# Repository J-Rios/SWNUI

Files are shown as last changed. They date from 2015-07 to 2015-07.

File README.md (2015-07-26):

# SWNUI
Simple Wireless Natural User Interface (Final Degree Project)

Inside the world of electronics there is a large diversity of fields, from among all, in this Final Degree Project, we will focus in the ambit of the human-machine interaction.

We will proceed then, to perform the prototype of a simple natural user interface that is able to make a wireless communication with an extern system, in our case a PC. To do that, we will use a microcontroller based system that will process the acquired reads from an accelerometer and determines the gesture accomplished to transmit it later through a Bluetooth link to the reception system.

In that way, we will start by implementing the hardware design of the system, designing the electrical schematic and the CAD design of the printed circuit board (by using the Eagle software), manufacturing the board and doing the components solder process. Once completed the hardware of the system we will continue with the software design, at both side of the system: the prototype manufactured and the extern system (PC), that allows verify the correct functionality of the system.

Complementary to the hardware and software development, we will work out the 3D model of the prototype enclosure (by using the Freecad software).

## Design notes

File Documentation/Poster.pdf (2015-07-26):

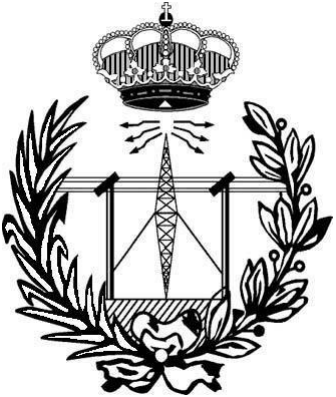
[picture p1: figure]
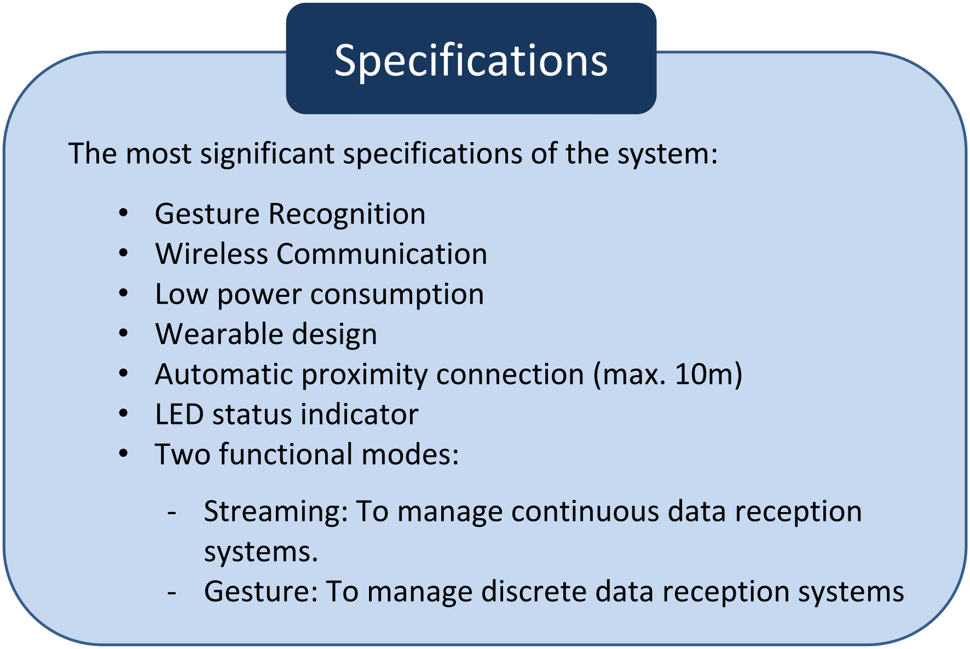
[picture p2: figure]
Specifications; • Gesture Recognition • Wireless Communication • Low power consumption • Wearable design; • LED status indicator • Two functional modes:; systems.

Inside the world of electronics there is a large diversity of fields, in this Final Degree Project, we will focus in the ambit of the human-machine interaction.
We will perform the prototype of a simple natural user interface that is able to recognizes hand gestures and control an extern system by wireless communication. To do that, we will use a microcontroller based system that will process the acquired reads from an accelerometer and determines the gesture accomplished to transmit it later through Bluetooth Low Energy link to the reception system.
We will start by implementing the hardware design of the system, designing the electrical schematic and the CAD design of the printed circuit board, manufacturing the board and doing the components solder process. Once completed the hardware of the system we will continue with the software design, at both side of the system: the prototype manufactured and the extern system (We will control the mouse and keyboard of a PC), that allows verify the correct functionality of the system.
Complementary to the hardware and software development, we will work out the 3D model of the prototype enclosure.

# Gesture Recognition System (Simple Wireless Natural User Interface)

## -José Miguel Ríos Rubio-

## Abstract

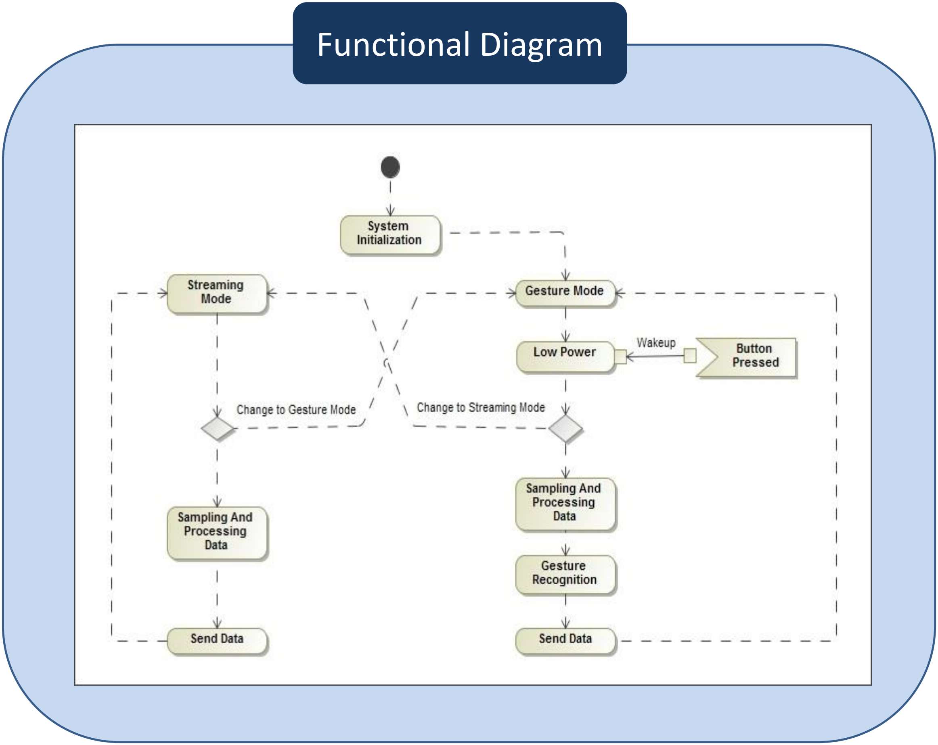
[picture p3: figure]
Functional Diagram
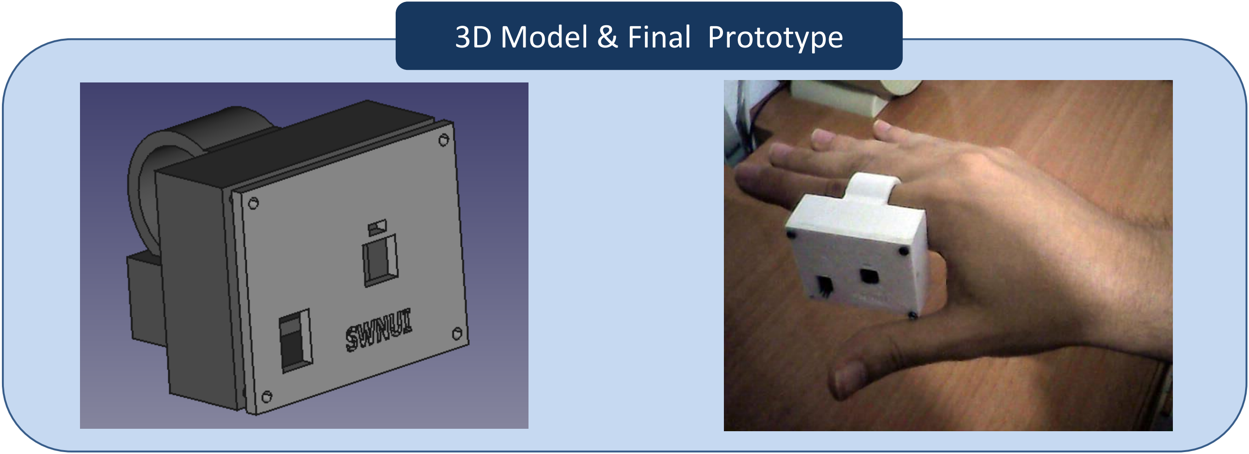
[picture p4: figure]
3D Model & Final Prototype
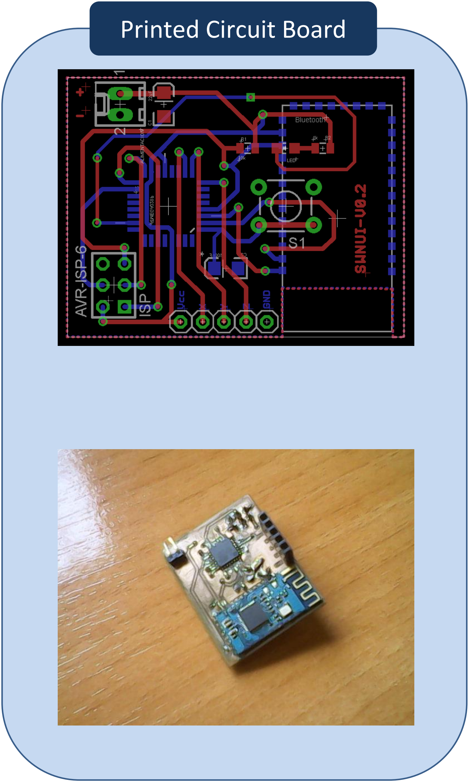
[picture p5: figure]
Printed Circuit Board

## Conclusions, Future Work and Repository

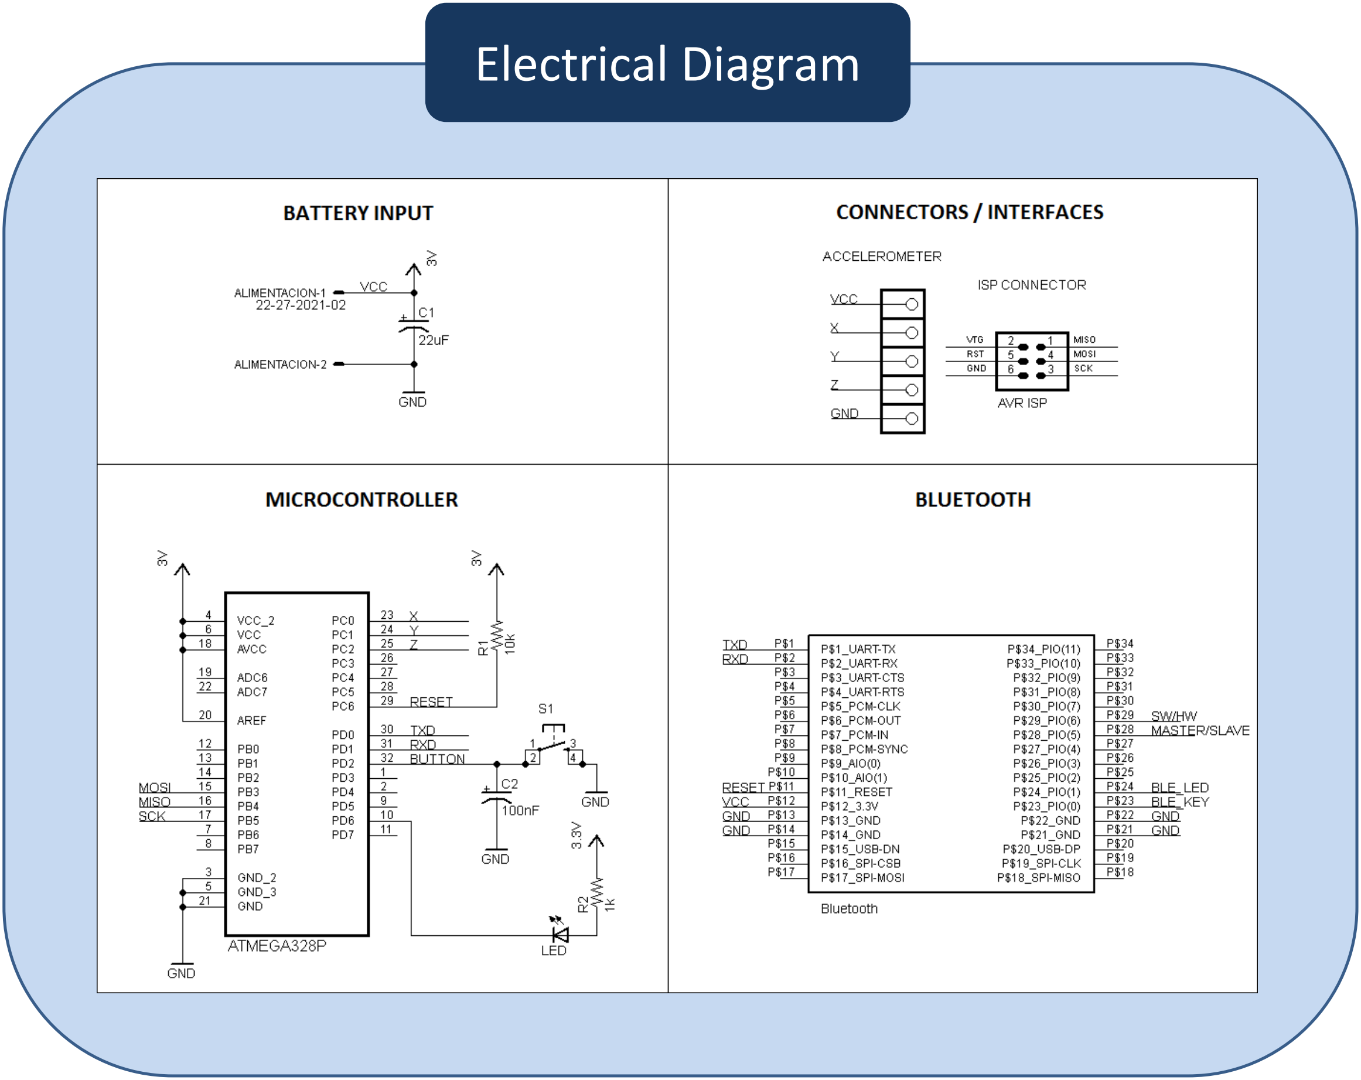
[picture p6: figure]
Electrical Diagram

## Future work

- Improve the low power of the system.
- Improve the mechanical part of the system (size and appearance).
- Design a SOC solution for all the system (Combine accelerometer, BLE and custom functionality).
- Transform the prototype into a final product.

## Departamento Tecnología Electrónica E.T.S.I Telecomunicación, Universidad de Málaga Trabajo Fin de Grado del Grado en Ingeniería de Sistemas Electrónicos. Julio 2015

The most significant specifications of the system:

- Automatic proximity connection (max. 10m)
- Streaming: To manage continuous data reception
- Gesture: To manage discrete data reception systems

## Conclusions

- IMU based solutions beats optical systems for gesture recognition (no need direct vision).
- Gesture recognition will become an important part of the wearables devices.
- NUIs will increase their importance in society (due rise of the wearable and low size MEMs technologies).

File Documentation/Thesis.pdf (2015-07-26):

## UNIVERSIDAD DE MÁLAGA

## ESCUELA TÉCNICA SUPERIOR DE INGENIERÍA DE TELECOMUNICACIÓN

## TRABAJO FIN DE GRADO

## SISTEMA DE RECONOCIMIENTO GESTUAL

GRADO EN INGENIERÍA DE
SISTEMAS ELECTRÓNICOS

JOSÉ MIGUEL RÍOS RUBIO
MÁLAGA, 2015

E.T.S. DE INGENIERÍA DE TELECOMUNICACIÓN, UNIVERSIDAD DE MÁLAGA

Título del Trabajo Fin de Grado

Autor: José Miguel Ríos Rubio

Tutor: Francisco Javier Vizcaíno Martín

Departamento: Departamento de Tecnología Electrónica

Titulación: Grado en Ingeniería de Sistemas Electrónicos

Palabras clave: Diseño hardware, Desarrollo software, Diseño CAD 3D, Sistema basado en microcontrolador, Sistema de interacción natural, Bluetooth Low Energy, Unidad de medida inercial (IMU)

Resumen

Dentro del mundo de la electrónica existe una gran diversidad de campos, de

entre todos ellos, en este trabajo fin de grado, nos centraremos en el ámbito de

la interacción humano-máquina.

Se procederá pues, a realizar el prototipo de un dispositivo de interacción

natural simple capaz de comunicarse de forma inalámbrica con un sistema

externo, en este caso un PC. Para ello, se recurrirá al uso de un sistema

basado en microcontrolador que procesará la lectura obtenida de un

acelerómetro y determinará el gesto realizado para, posteriormente, transmitirlo

a través de un enlace bluetooth al sistema receptor.

De este modo, comenzaremos por realizar el diseño hardware del sistema,

diseñando el esquema eléctrico y el diseño CAD de la placa de circuito impreso

(mediante el uso de la herramienta Eagle), para finalizar con el desarrollo de la

placa y el proceso de soldadura de componentes. Una vez finalizado el

hardware del sistema nos ocuparemos del diseño software, tanto de la parte

correspondiente al prototipo desarrollado como de la parte localizada en el PC,

la cual nos permitirá verificar el correcto funcionamiento del sistema.

Complementariamente al desarrollo hardware y software, crearemos el modelo

3D (gracias al software Freecad) de la carcasa que albergará al prototipo.

E.T.S. DE INGENIERÍA DE TELECOMUNICACIÓN, UNIVERSIDAD DE MÁLAGA

English version of the title

Author: José Miguel Ríos Rubio

Supervisor: Francisco Javier Vizcaíno Martín

Department: Departamento de Tecnología Electrónica

Degree: Grado en Ingeniería de Sistemas Electrónicos

Keywords: Hardware design, Software development, 3D CAD design, Microcontroller based system, Natural user interface system, Bluetooth Low Energy, Inertial measurement unit (IMU)

Abstract

Inside the world of electronics there is a large diversity of fields, from among all,

in this Final Degree Project, we will focus in the ambit of the human-machine

interaction.

We will proceed then, to perform the prototype of a simple natural user interface

that is able to make a wireless communication with an extern system, in our

case a PC. To do that, we will use a microcontroller based system that will

process the acquired reads from an accelerometer and determines the gesture

accomplished to transmit it later through a Bluetooth link to the reception

system.

In that way, we will start by implementing the hardware design of the system,

designing the electrical schematic and the CAD design of the printed circuit

board (by using the Eagle software), manufacturing the board and doing the

components solder process. Once completed the hardware of the system we

will continue with the software design, at both side of the system: the prototype

manufactured and the extern system (PC), that allows verify the correct

functionality of the system.

Complementary to the hardware and software development, we will work out

the 3D model of the prototype enclosure (by using the Freecad software).

# Agradecimientos

Haber llegado al punto de mi vida en cual me encuentro no ha sido un camino

fácil, no obstante, gracias a todas aquellas personas que han estado presente

a lo largo de mis estudios, ese camino se vio suavizado y se hizo más ameno.

Familia, amigos, compañeros, profesores… por vuestro tiempo, ayuda,

consejos y apoyo, gracias.

i

## Contenido

ii

iii

# Lista de Acrónimos

ADC | Analog-Digital Converter
BLE | Bluetooth Low Energy
CAD | Computer Aided Design
CNC | Control Numérico Computarizado
DOF | Degrees Of Freedom
DSP | Digital Signal Processing
FPGA | Field Programmable Gate Array
GPIO | General Purpose Input/Output
GPS | Global Positioning System
I2C | Inter-Integrated Circuit
ICSP | In Circuit Serial Programming
IDE | Integrated development environment
IMS | Inertial Measurement System
IMU | Inertial Measurement Unit
LED | Light Emitting Diode
MEMs | Microelectromechanical systems
PC | Personal Computer
PCB | Printed Circuit Board

iv

PCI | Placa de Circuito Impreso
POO | Programación Orientada a Objetos
RF | Radio Frecuencia
RTI | Rutina de Tratamiento de Interrupción
SMD | Surface Mounted Device
SPI | Serial Peripheral Interface
SWNUI | Simple Wireless Natural User Interface
TFG | Trabajo Fin de Grado
TPV | Terminal Punto de Venta
UART | Universal Asynchronous Receiver-Transmitter
UMA | Universidad de Málaga
USB | Universal Serial Bus

# Capítulo 1. Introducción

Desde el surgimiento de la especie humana y, mucho antes de la evolución del

lenguaje, la comunicación no verbal nos ha acompañado hasta hoy día. No obstante, el

estudio de ésta no alcanza una importancia digna de mención hasta la década de 1950,

en la que en el año 1952, el antropólogo Ray Birwhistell escribió “Introduction to

kinesics” [1], el cual es considerado como uno de los iniciales estudios modernos sobre

comunicación | no | verbal. | Ray | Birwhistell | acuñó | el | término | “kinesics”

(“kinésica”/”cinésica” en castellano), proveniente del griego kinesis, que significa

movimiento, para referirse al estudio del movimiento humano. De este modo, la

kinésica, junto con la “proxémica” (estudio de la forma de uso del entorno por parte de

la persona a la hora de comunicarse) y la “paralingüística” (estudio de las cualidades no

verbales de la voz) componen la base principal del lenguaje no verbal. Con lo cual, los

gestos pueden clasificarse en resumidas cuentas dentro de la “kinésica” del lenguaje

no verbal.

Se entiende como reconocimiento gestual la adquisición e interpretación de

movimientos de carácter expresivo del cuerpo o de partes del mismo. De esta forma, se

debe diferenciar claramente entre un movimiento, que puede o no tener significado, y

un gesto, cuyo carácter significativo se encuentra intrínsecamente ligado a su acción.

Normalmente, los gestos presentan la funcionalidad de permitir la comunicación no

verbal entre dos seres que comparten la misma interpretación para el conjunto de

señales que conforman el lenguaje gestual, y decimos “normalmente” pues suele haber

casos en los que el gesto suele ir acompañado de algún sonido característico

("paralingüismo"). Una clara distinción entre comunicación verbal y no verbal radica en

el hecho de que el primero es utilizado para comunicar información mientras que el

Capítulo 1. Introducción

segundo es usado para comunicar estados de ánimo y/o actitudes respecto a un

acontecimiento.

## 1.1. Contexto tecnológico

Determinar la posición y el movimiento en el espacio de una entidad es de gran importancia para una gran variedad de aplicaciones. Si observamos hoy día el mercado actual nos encontramos en medio de una batalla comercial en la que se intenta hallar qué sistema de captura y reconocimiento de movimiento es el más eficientemente aceptado por la sociedad y, consecuentemente, el más exitoso.

Las empresas relacionadas con los videojuegos fueron las que, en primera instancia, se abrieron paso en este mundo en busca de la mejora en la experiencia de juego de los usuarios, intentando encontrar una interfaz con la que el jugador pudiera interaccionar de forma innovadora y más cercana a la realidad. Entre los dispositivos más reconocidos y que mayor impacto han tenido se encuentran, entre otros (figura 1), el Sensor Kinect [2] de Microsoft, lanzado el 4 de noviembre de 2010 [3], que entró en el “Guinness World Records” (Libro Guinness de los Records) por ser el periférico de juego vendido más rápidamente tras vender una media de 133.333 unidades por día en sus primeros 60 días [4]. Básicamente, este dispositivo es un periférico de control para la videoconsola Xbox 360, aunque posteriormente se adaptase para su uso en PC con sistemas operativos Windows 7 y Windows 8. El Sensor Kinect se encuentra en competencia directa con el Wii Remote [5] de Nintendo y el PlayStation Move [6] de PlayStation de los que hablamos a continuación.

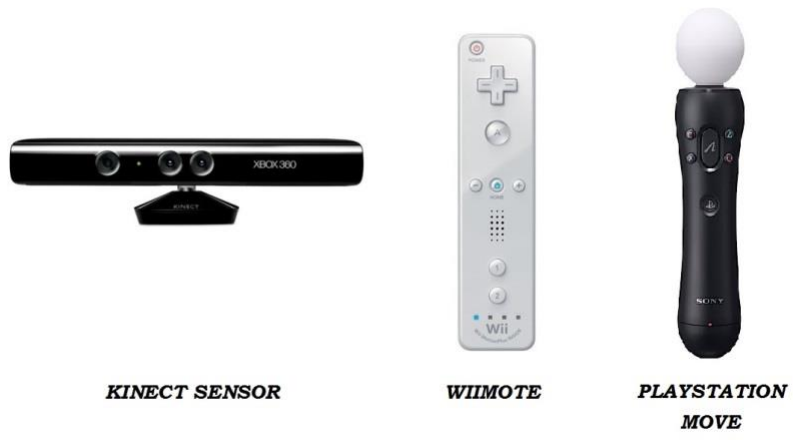
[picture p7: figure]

Figura 1. Dispositivos de reconocimiento gestual (Kinect, Wiimote y PlayStation Move).

El Wii Remote fue desarrollado como periférico de control de la videoconsola Nintendo Wii y, apareció en el mercado junto con esta, el 19 de noviembre de 2006 [7].

Introducción

Por otro lado, el PlayStation Move es un sistema conformado por un dispositivo de control, Motion Controller, y un dispositivo basado en una cámara, PlayStation Eye, que se encarga de obtener la posición del dispositivo de control. El sistema salió al mercado el 17 de septiembre de 2010 [6].

Sin embargo, no solo las empresas dedicadas al entretenimiento están interesadas en el uso de este tipo de sistemas de reconocimiento de movimiento. Determinar la posición y el movimiento en el espacio de una entidad es de gran importancia para una gran variedad de aplicaciones en distintos campos. Parte de la característica más destacable de los teléfonos inteligentes (Smartphones) de hoy en día consiste en la detección de la orientación, inclinación y aceleración que sufren, todo esto es gracias a la incorporación de dichos sistemas de reconocimiento en estos dispositivos. Así mismo, un gran número de aplicaciones robóticas se basan en el uso de estas tecnologías sensoriales para realizar el control del movimiento de las distintas partes del robot o mecanismo asociado. Esto se extiende desde el manejo de Drones (vehículos aéreos no tripulados controlados remotamente) en aplicaciones militares, control de un robot de alta precisión para realizar operaciones quirúrgicas (campo de medicina y salud) como el Sistema Quirúrgico Da Vinci [8], dispositivos de ayuda a la navegación de vehículos (sobre todo aéreos), etc.

En la actualidad, el reconocimiento gestual se encuentra extendido entre dos tipos de tecnologías de adquisición e interpretación de gestos: las basadas en “cámara”, las cuales pueden considerarse ópticas, que requieren de un procesamiento gráfico y, por consiguiente, de visión directa del gesto (como el Sensor Kinect y el PlayStation Move), y los basados en sistemas de “unidad de medida inercial” (IMU, de sus siglas en inglés “Inertial Measurement Unit”), no ópticas, como el Wii Remote.

Los sistemas “ópticos” de reconocimiento de movimiento pueden o no servirse de algún dispositivo auxiliar al que realizar el seguimiento y determinar el movimiento realizado (como en el caso del Motion Controller de PlayStation) o no (Kinect de Microsoft), dado que estos sistemas están ampliamente ligados más al algoritmo software de reconocimiento y procesado de imagen. Cuanto más complejo sea dicho procesado mayor potencia tendrá el sistema. De esta forma, el Sensor Kinect es un dispositivo cuyo procesado de reconocimiento es tan potente que permite reconocer no solo al usuario que está interactuando, sino obtener cada uno de los movimientos realizados por este. No obstante, y como es de esperarse debido a que el sistema requiere de visión directa, si el usuario oculta sus manos tras la espalda y realiza algún movimiento con ellas esto no será detectado por el sistema.

En contraposición, las unidades de medida inercial o IMUs son dispositivos electrónicos que albergan un conjunto de sensores que permiten identificar al dispositivo en el

Capítulo 1. Introducción

espacio mediante la adquisición de ciertos parámetros de aceleración, inclinación, orientación y posición. Para ello, estos sistemas pueden presentar diferentes tipos de sensores: acelerómetros, giroscopios, magnetómetros (basados en tecnologías de sistemas microelectromecánicos, MEMs), barómetros e incluso GPS (Sistema de posicionamiento global).

Los acelerómetros son sistemas capaces de medir la aceleración lineal, los giroscopios permiten determinar la velocidad angular, los magnetómetros permiten detectar campos magnéticos (como el de la Tierra), los barómetros indican la presión barométrica (en relación a la altitud) y el GPS determina la posición del sistema según las coordenadas terrestres de longitud, latitud y altitud, así como de proveer de parámetro temporal al sistema (tiempo).

Según la presencia de dichos sensores en la IMU y el número de ejes de medida de tales elementos, un sensor inercial puede ser clasificado, según los grados de libertad, por las siglas DOF (“Degrees of freedom”) del mismo. Así, si una IMU tiene 6 DOF, ésta suele estar compuesta por un acelerómetro y un giroscopio de 3 ejes cada uno (‘X’, ‘Y’ y ‘Z’). En caso de que la IMU sea de 9 DOF, el sistema contendrá a su vez un magnetómetro.

Figura 2. Ejemplo de IMU de 11 DOF (Con GPS y Barómetro incluidos).

Puede considerarse que cualquier extremidad del cuerpo humano tiene como máximo 6 grados de libertad de movimiento, que permiten determinar la posición y orientación de esa parte en el espacio.

Todo avión que sobrevuela en la actualidad nuestros cielos presenta un sistema de medición inercial (IMS), el cual cuenta con una unidad de medida inercial (IMU) para

Introducción

corregir la inclinación (de forma automática) y, por tanto detectar cualquier malfuncionamiento, como avisar al piloto de cualquier peligro existente.

Conociendo estos dos tipos de tecnologías de reconocimiento de movimiento, podemos volver a analizar los productos de entretenimiento antes expuestos (Kinect, Wii Remote y PlayStation Move) para determinar cuál tecnología es aplicada a cada uno de ellos. De esta forma, el Sensor Kinect está basado exclusivamente, como ya hemos dicho, en el reconocimiento óptico, el Wii Remote por el contrario, es un sistema puramente basado en IMU, mientras que el PlayStation Move representa la fuerza de la unión de ambas tecnologías en el mismos sistema (sistema híbrido) ya que su Motion Controller presenta una IMU que determina aspectos de movilidad semejantes a los del Wii Remote mientras que, el PlayStation Eye, añade un reconocimiento visual de nuestros movimientos.

## 1.2. Objetivos del Trabajo Fin de Grado

Visto todo lo anterior, el objetivo principal de este trabajo fin de grado consiste en

realizar un sistema de interacción natural de usuario (NUI, del inglés Natural User

Interface) simple y de bajo coste. Para ello se procederá al desarrollo del prototipo de

un elemento capaz de registrar e interpretar un conjunto de simples gestos

(movimientos e inclinaciones), realizados por la mano del usuario, con el fin de

controlar de forma inalámbrica diversos sistemas externos sin que exista una visión

directa entre la mano y el sistema.

## 1.3. Estructura de la Memoria

El documento presente se encuentra dividido en varios capítulos que muestran el conjunto de contenidos desarrollados para realizar la implementación del sistema. A continuación, se procede a describir el contenido de cada uno de esos capítulos, de esta forma:

- En el primer capítulo (“Introducción”), el presente, se ha hablado del ámbito de este Trabajo Fin de Grado (TFG). Se ha intentado dar una pincelada muy general del TFG, comenzando por el desarrollo de una breve introducción relativa a la temática del proyecto, el contexto tecnológico actual de diversas tecnologías y productos relacionados con el sistema a desarrollar y acabando con los objetivos principales de dicho sistema y la estructura del documento.

Capítulo 1. Introducción

- El capítulo segundo (“Especificaciones del sistema”), concierne a las especificaciones del sistema donde, analizando el objetivo que debe cumplir el mismo, se fijan las características que presentará el sistema y se establecen los requisitos que se pretenden cumplir.
- En el tercer capítulo (“Desarrollo del sistema”), se determina los componentes a utilizar para el diseño del sistema y se muestra todo el proceso de diseño y desarrollo y fabricación del prototipo del sistema realizado, pasando por el hardware, el software y el diseño CAD de la carcasa.
- En el capítulo cuarto (“Verificación y pruebas”) se define el conjunto de pruebas a realizar sobre el sistema desarrollado, el proceso de realización de tales pruebas y el resultado de las mismas, verificándose así la correcta funcionabilidad del sistema y el cumplimiento de los objetivos y especificaciones del proyecto.
- El quinto capítulo (“Manual de instalación y uso”), alberga el contenido relacionado con la instalación, puesta en marcha y utilización del sistema mediante la redacción de ciertos manuales de usuario.
- El capítulo sexto (“Conclusiones y trabajo futuro”) expone el conjunto de experiencias adquiridas en la realización del proyecto, así como un análisis de prestaciones del sistema, indicando las posibles mejoras que se podrían incorporar al prototipo realizado.

# Capítulo 2. Especificaciones del sistema

Dado que nuestro sistema es un dispositivo de interacción natural (NUI) que

nos va a permitir determinar gestos simples y comunicarlos de forma

inalámbrica, se le dará al sistema el nombre SWNUI (Simple Wireless Natural

User Interface) de aquí en adelante.

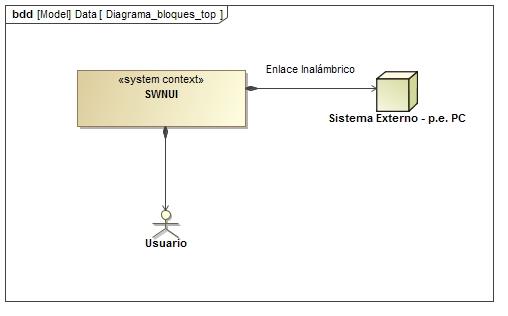
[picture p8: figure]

Figura 3. Contexto del sistema.

Según el objetivo de nuestro proyecto, el sistema permitirá el reconocimiento

de los gestos realizados con la mano sin la necesidad de que exista visión

directa entre el elemento de control y el sistema a controlar. Además, el

sistema deberá ser capaz de comunicarse de forma inalámbrica con ese

Capítulo 2. Especificaciones del sistema

elemento externo (figura 3). Lo que nos lleva a acotar ciertas características

que poseerá nuestro sistema:

- Podemos determinar que, dado que no se precisa visión directa, el tipo

de tecnología a utilizar será el basado en IMUs (tecnología “no óptica”).

- Ya que los gestos a registrar se realizan con la mano, sabemos que el

IMU se debe situar en algún punto de la misma.

- La comunicación deberá ser inalámbrica y de un rango de alcance

medio/alto. Entre ellos podría usarse RF, bluetooth, Zigbee, wifi, etc.

Por otro lado, el sistema buscará la armonía entre bajo consumo y tamaño

reducido para satisfacer la tendencia actual hacia la creación de dispositivos

wearables (“vestibles”):

- Esto implica que el sistema deberá encontrarse en un estado de bajo

consumo el máximo tiempo posible y se activará para realizar el proceso

de registro, procesado y envío del gesto realizado.

- La activación del sistema, por tanto, no dependerá del movimiento

realizado sino que se llevará a cabo a partir de un pulsador.

- Dado que el sistema será de pequeño tamaño y wearable, el pulsador

de activación se debe localizar en una posición confortable para la

pulsación por el usuario (que se evite el tener que recurrir a la otra mano

para su uso), determinamos que la posición óptima del sistema se

encontrará en el dedo índice de la mano, con pulsación mediante el

dedo pulgar (figura 4).

- El bajo consumo junto al bajo coste limitaría el tipo de tecnología de

comunicación inalámbrica a utilizar: RF, BLE…

Figura 4. Pulsador en posición confortable.

Capítulo 2. Especificaciones del sistema

Analizando el objetivo del sistema en sí, podemos apreciar que, registrar los

datos de movimientos e inclinaciones realizados continuamente es un paso

previo a la obtención del gesto realizado, por lo que si el sistema que queremos

controlar es un sistema dinámico (requiere un flujo continuo de datos para su

control, por ejemplo controlar el movimiento de un robot o un dron, o manejar el

cursor de un ordenador) incluir un modo de funcionamiento continuo,

conmutable con el modo de envío de gestos, no es mala idea:

- Por tanto, se implementarán dos modos de funcionamiento del sistema,

el modo de envío continuo de datos y el modo de envío de gestos.

- El modo de funcionamiento debe ser señalizado para el usuario, por

ejemplo mediante un LED.

- Dado que el sistema incluye un pulsador para salir del bajo de consumo,

con el fin de no incrementar el coste, éste también se utilizará para

realizar el cambio entre modos.

Analizando más detenidamente la tecnología necesaria tanto para el IMU,

como para el enlace inalámbrico, conseguimos determinar que:

- Como los gestos a registrar son sencillos (inclinación y movimiento), el

IMU se reduce a un simple acelerómetro de tres ejes.

- Ya que el sistema debe de ser de bajo consumo y la velocidad de

transmisión de datos no necesita ser muy alta, la comunicación

inalámbrica se puede satisfacer mediante Bluetooth Low Energy (BLE).

Los movimientos voluntarios de una mano suelen ser inferiores a los 7 Hz [9],

por lo que la frecuencia de muestreo deberá ser superior a los 14 Hz (para

cumplir con el teorema de Nyquist). De este modo, la frecuencia no será una

limitación a la hora de seleccionar el elemento de procesamiento de nuestro

sistema:

- Cualquier microcontrolador de gama baja/media (8 bits), poseerá la

velocidad de procesamiento suficiente para cumplir con el muestreo de

datos.

- Del mismo modo, el microcontrolador deberá tener los periféricos

adecuados para poder comunicarse con el acelerómetro (GPIO, SPI,

I2C…), así como con el módulo BLE (UART).

Capítulo 2. Especificaciones del sistema

Partiendo del objetivo de nuestro sistema, hemos identificado las necesidades

ligadas al mismo, lo que permite distinguir entre las distintas especificaciones

que tendrá el sistema, delimitando las tecnologías apropiadas para su

implementación. Así pues, resumiendo todo lo anterior, podemos enumerar los

elementos y tecnologías que compondrán nuestro sistema:

- Núcleo de procesamiento: Microcontrolador.
- Unidad de medida inercial: Acelerómetro de tres ejes.
- Comunicación inalámbrica: Modulo transceiver BLE.
- Entrada de usuario: Pulsador.
- Indicación al usuario: LED.

Por tanto, el diagrama de bloques internos del sistema quedará como el

representado en la figura 5.

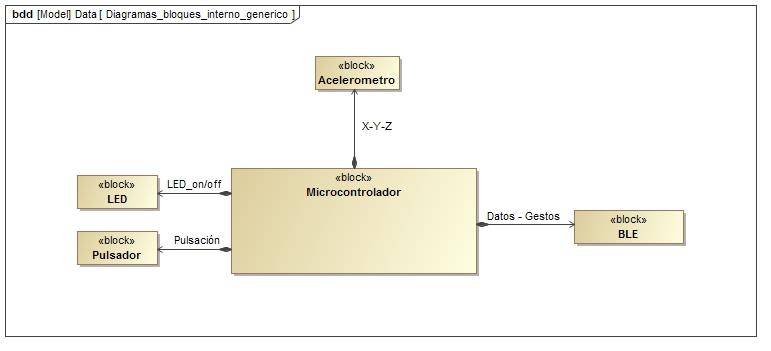
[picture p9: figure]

Figura 5. Pulsador en posición confortable.

Llegados a este punto, podemos determinar cuál será la funcionalidad

completa de nuestro sistema. El sistema presentará dos modos de

funcionamiento, llamémoslos “modo continuo” y “modo gestos”, conmutables

entre sí a partir del pulsador del sistema. Por otro lado, el LED establecerá una

indicación visual para el usuario dando a entender en qué modo se encuentra

el sistema. El “modo continuo” del sistema enviará a través del módulo BLE, de

forma continua, los datos correspondientes a la posición y movimiento de la

Capítulo 2. Especificaciones del sistema

mano, mientras que el “modo gestos” introducirá al sistema en un estado de

bajo consumo del que, al presionar y mantener pulsado el pulsador, se saldrá

para muestrear y procesar los gestos realizados por la mano y, al soltar el

pulsador, estos se enviarán por el módulo BLE.

Toda la funcionalidad genérica de nuestro sistema, expuesta en el párrafo

anterior, se muestra en la siguiente imagen (figura 6) mediante su diagrama de

actividad (diagrama de flujo).

Figura 6. Pulsador en posición confortable.

La funcionalidad del sistema, así como el uso y manejo del mismo, se recogerán de forma exacta en el apartado de manuales de instalación y uso del presente documento (capítulo cinco). Además, una vez desarrollado el prototipo, los dos modos de funcionamiento del sistema se verificarán de forma apropiada en el apartado de pruebas y verificación (capítulo 4).

Capítulo 2. Especificaciones del sistema

## 2.1. Requisitos

Habiendo determinado las especificaciones que deberá tener el sistema,

procederemos a establecer los requisitos que permitirán el cumplimiento de

esas especificaciones.

Id. | Nombre | Descripción | Tipo | Prioridad

1

Función del sistema | Procesar y determinar gestos realizados
| a partir del acelerómetro

Funcional

10

2

Comunicación

inalámbrica

Transmitir gestos de forma inalámbrica a

través de Bluetooth Low Energy

Funcional | 10

3

Conexión automática | El enlace Bluetooth se establece

automáticamente (en “segundo plano”)

Funcional | 7

4

Modo continuo | Modo de funcionamiento continuo

(Streaming de datos)

Funcional | 8

5

Modo gestos | Modo de funcionamiento discreto (Envío

de gestos aislados)

Funcional | 9

6

Cambio de modo | Cambiar modos de forma directa por el

usuario mediante el pulsador

Funcional | 7

7

Bajo consumo | Porcentaje de tiempo en bajo consumo

en el modo gestos superior al 85%

Funcional/Prestación 8

8

Autonomía | Tiempo de batería en modo continuo

superior a 10h

Prestación | 7

9

Diseño Wearable | Tamaño no superior a 5 cm³
y portable

en el dedo índice

Prestación | 6

10

Indicación de modo Incorporar un LED señalizador del modo

actual del sistema

Funcional/Prestación 8

11

Batería ligera | Alimentación del sistema mediante

baterías no superiores en tamaño a dos

AAA

Prestación | 7

Tabla 2.1. Tabla de descripción de requisitos

Capítulo 2. Especificaciones del sistema

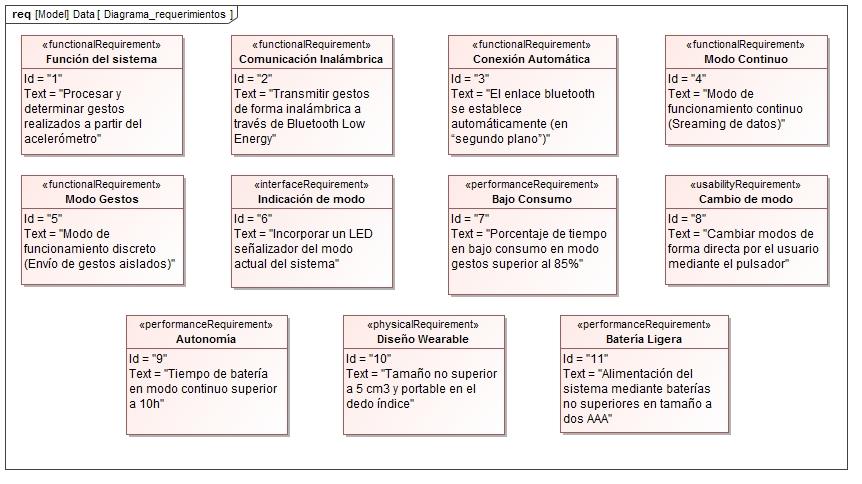
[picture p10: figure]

Figura 7. Diagrama SYSML de requisitos del sistema.

Capítulo 2. Especificaciones del sistema

# Capítulo 3. Desarrollo del sistema

Habiendo definido las especificaciones del sistema y los requisitos que este

presentará, así como las tecnologías a utilizar, salimos del nivel del ingeniero

de sistemas y entramos de lleno en el proceso de desarrollo del sistema. De

esta forma, comenzaremos por determinar los elementos exactos, que se

adecuan | a | las | tecnologías | establecidas | anteriormente, | a | utilizar.

Continuaremos por el diseño y desarrollo del hardware del sistema (esquema

eléctrico y fabricación de la placa de circuito impreso) y el desarrollo software

de la funcionalidad del sistema. Y, acabaremos por el proceso de creación del

modelo 3D de la carcasa que almacenará al sistema.

## 3.1. Selección de componentes

Para satisfacer de cierta manera el bajo precio del sistema al mismo tiempo

que se mantiene un tamaño reducido, buscamos ajustar los elementos del

sistema para que sean directamente compatibles con la batería del mismo, sin

necesidad de ningún subsistema de regulación de la tensión (evitaremos el uso

de elevadores o reductores de tensión).

Figura 8. Baterías Energizer AAA.

Capítulo 3. Desarrollo del sistema

Ya que fijamos como requisito que la batería del sistema tuviera un tamaño

máximo de dos pilas AAA (figura 8), se ha decidido colocar dos pilas de este

tipo en serie como alimentación del sistema. Esto podría suministrar una

tensión de alimentación de 3V, una capacidad superior a 1 mAh y una corriente

máxima de entrega superior a los 500 mA (capacidad y pico de corriente

demandable dependientes del tipo de batería) [10].

Por tanto, teniendo en cuenta estas baterías como sistemas de alimentación,

debemos buscar elementos cuyos límites de operación vayan desde un valor

máximo de 3V a un valor mínimo de unos 2.5V (tensión a partir de la cual la

curva de caída de tensión de las baterías se acentúa de forma considerada).

Figura 9. Módulo ADXL335. Acelerómetro de 3 ejes.

En el apartado anterior, determinamos que el papel del IMU lo tomará un único

acelerómetro y, dado que buscamos un bajo coste y que la gran exactitud del

sistema no es completamente necesaria, podemos recurrir a un acelerómetro

analógico (el cual no presenta ningún procesado de las muestras que mide,

cosa que aumenta el precio, como en el caso de los acelerómetros digitales). El

acelerómetro seleccionado es el ADXL335 (figura 9), definido según su

datasheet [11] como un acelerómetro de tres ejes, ±3g, pequeño, de bajo

consumo y salida condicionada de voltaje. Además, el voltaje de operación del

mismo permite la alimentación directa de los 3V (voltaje de alimentación: 1.8 V

– 3.6 V).

Capítulo 3. Desarrollo del sistema

Figura 10. Módulo BLE-CC41 Bolutek. Acelerómetro de 3 ejes.

Cuando analizamos las especificaciones del sistema, concluimos que la

comunicación inalámbrica sería satisfecha mediante la tecnología Bluetooth

Low Energy (BLE). Dentro de esta tecnología, existen módulos “transceivers”

conversores de comunicación serie a BLE. El módulo más barato que en la

actualidad puede obtenerse es el módulo BLE-CC41 de Bolutek (figura 10)

[12]. Este módulo BLE, de clase II, se basa en el SOC (System On Chip) de

Texas Instrument CC2541 [13], una solución de Bluetooth Low Energy y

comunicaciones propietarias de 2.4 GHz. Por supuesto, el módulo tiene un

rango de alimentación apto para nuestra batería (voltaje de alimentación: 2 V –

3.6 V).

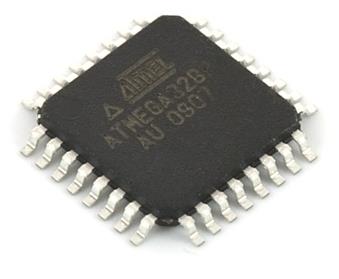
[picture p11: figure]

Figura 11. Microcontrolador ATMEGA328P-AU.

El microcontrolador a utilizar en nuestro sistema debe proporcionar los

periféricos necesarios para poder utilizar tanto el sensor de aceleración

(GPIOs) como el módulo de comunicación BLE (UART). Dado que cualquier

Capítulo 3. Desarrollo del sistema

microcontrolador existente presenta puertos de entrada/salida, la elección del

microcontrolador se reducirá a uno que presente algún puerto de comunicación

serie y permita una tensión de alimentación compatible con el sistema de

baterías. Dentro del abanico tan amplio de selección, optamos por el

microcontrolador ATMEGA328 de Atmel (figura 11) [14], el cual posee UART y

una tensión de alimentación apta (tensión de alimentación: 1.8 V – 5.5 V). El

ATMEGA328 es el microcontrolador utilizado en la plataforma Arduino estándar

(Arduino Uno) [15]. Este es el motivo de su elección, ya que se le puede cargar

el bootloader de Arduino, que nos permitirá el uso de su capa de abstracción

hardware a la hora de programar nuestro sistema.

## 3.2. Desarrollo hardware

Una vez determinados los componentes electrónicos a utilizar en nuestro

proyecto, procedemos a la elaboración del diseño hardware del sistema

(mediante el software de diseño CAD Eagle [16]), empezando por el esquema

eléctrico.

El esquema eléctrico de nuestro sistema se puede observar en la siguiente

imagen (figura 12).

Figura 12. Esquema eléctrico del sistema.

Capítulo 3. Desarrollo del sistema

El microcontrolador obtiene los datos del acelerómetro (pines ‘X’, ‘Y’ y ‘Z’ para

cada eje) y los procesa (determinando el gesto realizado) para, posteriormente,

enviar un comando correspondiente por el puerto serie (pines RXD y TXD)

hacia el módulo BLE, el cual se encargará de transmitirlo.

El método seguido en el diseño eléctrico para permitir la programación del

microcontrolador es el basado en ICSP (In Circuit Serial Programming). Este

método de programación serie que utiliza el puerto SPI del microcontrolador,

fue diseñado para permitir la programación de microcontroladores que se

encuentran ya integrados en sistemas, sin necesidad de que estos deban ser

extraídos del mismo. Por ello, en nuestro sistema eléctrico añadimos el llamado

conector ICSP (figura 13) en su versión de seis pines (existe la versión de diez

pines) para ahorrar tamaño.

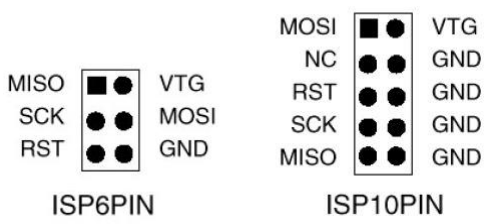
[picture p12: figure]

Figura 13. Conectores ICSP.

Con el fin de ahorrarnos componentes innecesarios y, ya que no se precisa de

una gran velocidad de operación, el microcontrolador se programará con el

Bootloader de Arduino a una frecuencia interna del sistema de 8 MHz. Esto nos

evitará el uso de un resonador externo (cristal y condensadores) debido a que

se configura para que el reloj del sistema se genere a partir del oscilador

interno del mismo microcontrolador.

Otro aspecto a tener en cuenta en nuestro circuito, sería la conexión del pin

AREF (tensión del conversor ADC) del microcontrolador a la tensión de

alimentación, pues necesitaremos realizar la lectura de los valores analógicos

del voltaje de cada eje del acelerómetro para determinar los datos de

aceleración de forma correcta.

Capítulo 3. Desarrollo del sistema

El pulsador del circuito es una parte fundamental del mismo ya que cumple un

rol fundamental en la funcionalidad del sistema. Por este motivo, con el fin de

evitarnos posibles problemas a la hora de gestionar de manera software los

posibles rebotes que se producen, procedemos a incluir un condensador que

filtre tales rebotes de manera hardware. Por otro lado, haciendo uso de la

resistencia de “pull-up” interna del pin del microcontrolador, podremos

ahorrarnos la resistencia externa que fije el nivel lógico “alto”.

Figura 14. Pulsador con anti-rebote.

Como se puede observar, en el circuito eléctrico, se han añadido dos

resistencias tanto para el pin de RESET del microcontrolador (resistencia para

fijar un nivel lógico “alto”, de valor típico de 10k según el fabricante), como para

el LED (resistencia que limitará el flujo de corriente). A continuación

procedemos a realizar el cálculo del valor de resistencia óptimo para que el

LED brille a una intensidad adecuada sin que sea un potencial elemento de

consumo de corriente en nuestro sistema (2 mA):

LED (I = 2mA) → R =

VCC − VLED
I

=

3 − 1.3
0.002 = 850 Ω ≈ 1 KΩ

La tensión de 1.3 V de caída del LED se ha obtenido por medición del mismo

(figura 15), ya que el LED a utilizar en el sistema debe poseer una tensión de

caída en directa (VFordward) muy baja, dada nuestra tensión de alimentación de

3V.

Capítulo 3. Desarrollo del sistema

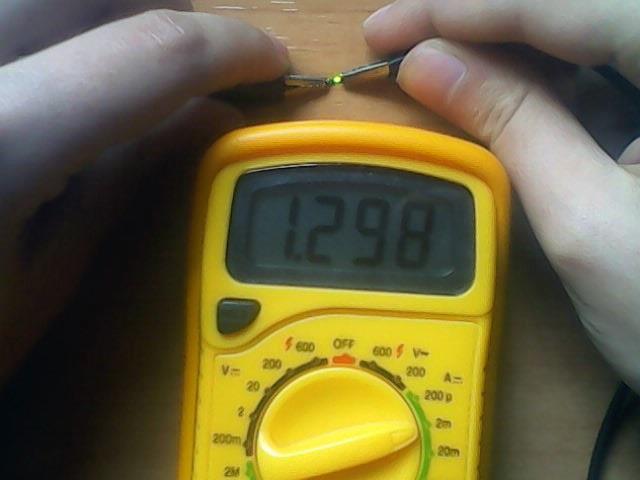
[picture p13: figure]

Figura 15. Medición de caída de tensión en el LED.

Una vez que tenemos diseñado el esquema eléctrico de nuestro circuito y

habiendo repasado los diversos aspectos dignos de mención sobre el mismo,

procedemos a diseñar la placa de circuito impreso.

Teniendo en mente el requisito del diseño wearable, de pequeño tamaño del

sistema, determinamos que, a excepción del pulsador, el resto de

componentes del circuito deberán ser de montaje superficial (SMD), además la

PCI tomará el menor tamaño posible.

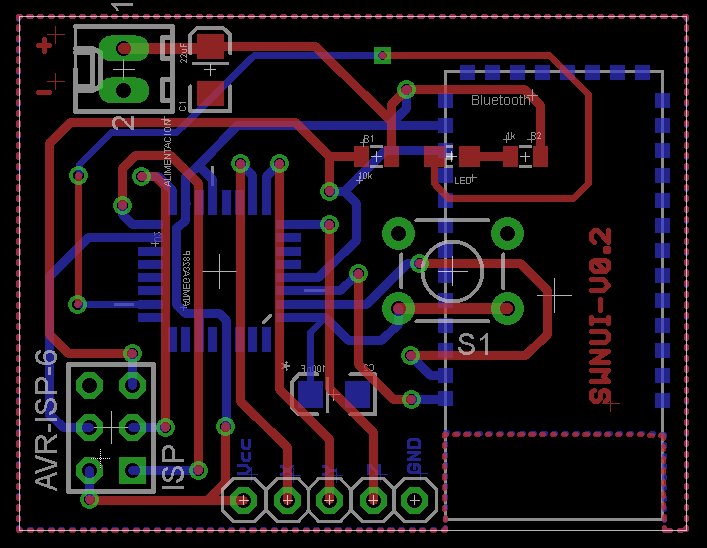
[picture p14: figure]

Figura 16. Diseño CAD de la placa de circuito impresa.

Capítulo 3. Desarrollo del sistema

Conservando la idea del tamaño reducido de placa, conseguimos el resultado

que se puede ver en la figura anterior (figura 16). La placa final es a doble cara,

de un tamaño de 4x3 cm de lado y un ancho de pista de 0.5 mm.

Finalizado el diseño CAD de la placa de nuestro sistema, se exportaron los

archivos gerbers y excellons adecuados y se enviaron para su fabricación

(mediante la fresadora CNC de la UMA). El resultado del proceso de

manufactura fue el siguiente (figura 17):

Figura 17. Placa de circuito impreso.

La fabricación de la placa mediante una fresadora, a pesar de su resultado

óptimo, presenta un inconveniente, las vías no son metalizadas. Esto implica

que a la hora de soldar se debe prestar mucha atención para interconectar a

través de las vías las pistas correspondientes de ambas caras. Para ello,

procedemos a introducir pequeños fragmentos correspondientes a terminales

de componentes electrónicos discretos (por ejemplo sobrantes de resistencias)

en cada vía y los soldamos. Una vez realizado esto en cada orificio pertinente,

se lija las soldaduras obtenidas con el fin de eliminar el volumen vertical de las

mismas, las cuales podrían entorpecer el proceso de soldadura de otros

componentes (como en el caso del microcontrolador si hubiéramos diseñado

vías en el interior de su emplazamiento). Estas soldaduras de unión en las vías

son el primer paso en el proceso de soldadura del resto de componentes, así,

lo siguiente sería las soldaduras de los componentes smd, empezando por el

microcontrolador y el módulo BLE, seguido de las resistencias, el LED y los

condensadores; y acabando con los componentes de mayor tamaño, es decir,

Capítulo 3. Desarrollo del sistema

el pulsador y los pines que conforman los conectores de alimentación,

programación y el acelerómetro.

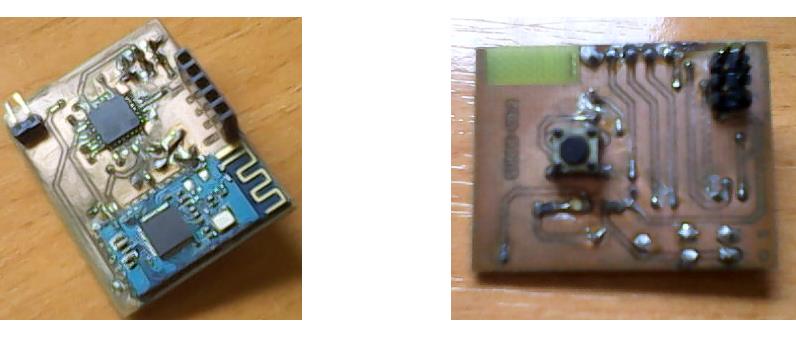
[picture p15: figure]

Figura 18. Placa de circuito impreso tras el proceso de soldadura.

La imagen anterior (figura 18) muestra el resultado final de la placa de circuito

impreso tras haber soldado todos los componentes del mismo. Esto concluye

con el desarrollo hardware del sistema y nos abre la posibilidad de comenzar a

programar nuestro sistema.

## 3.3. Desarrollo software

### 3.3.1. Configurando el entorno de programación

Como mencionamos anteriormente, el sistema se programará mediante el

puerto ICSP a través del entorno de programación de Arduino. El dispositivo

utilizado para la programación es el llamado USBasp [17], un programador

ICSP de microcontroladores de Atmel de bajo precio (figura 19).

Figura 19. USBasp.

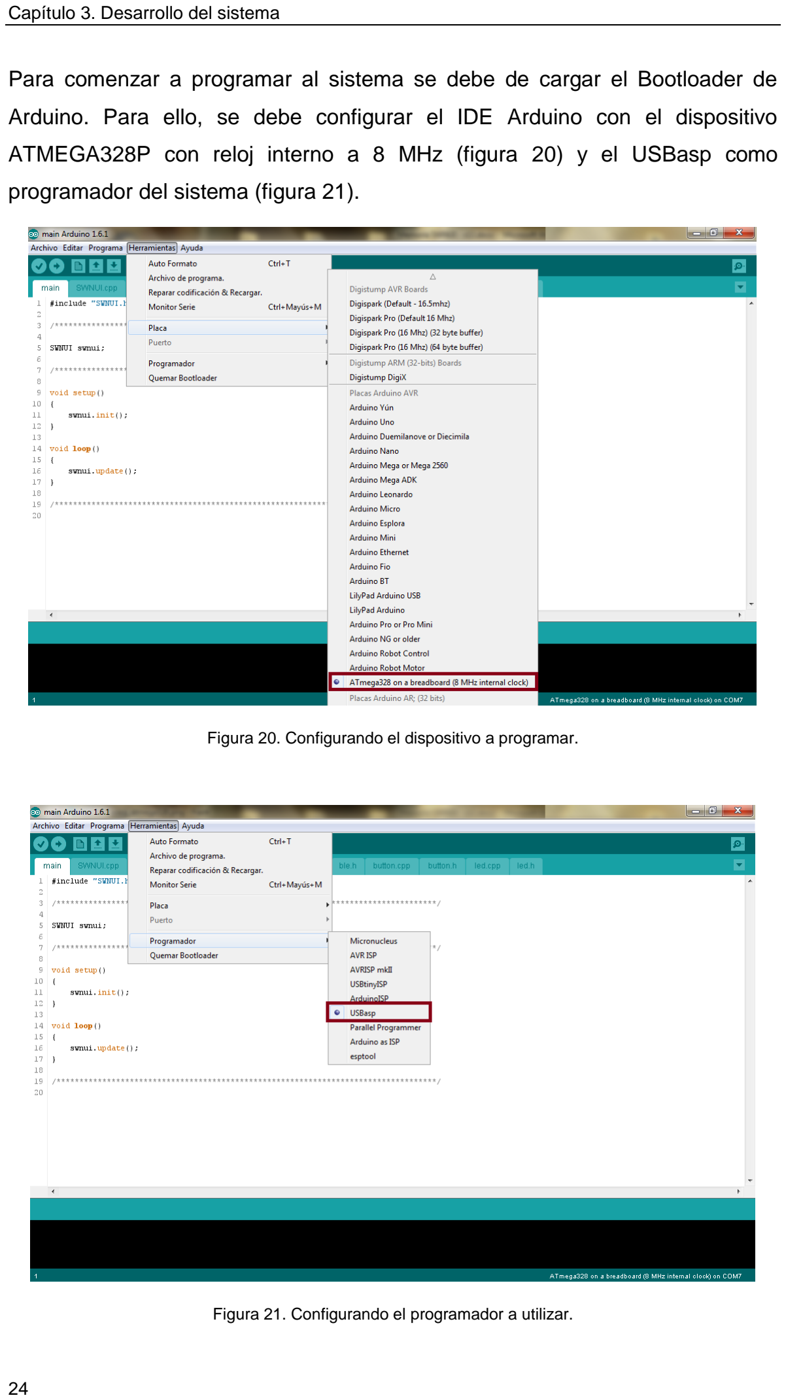
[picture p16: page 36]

Capítulo 3. Desarrollo del sistema

Para comenzar a programar al sistema se debe de cargar el Bootloader de

Arduino. Para ello, se debe configurar el IDE Arduino con el dispositivo

ATMEGA328P con reloj interno a 8 MHz (figura 20) y el USBasp como

programador del sistema (figura 21).

Figura 20. Configurando el dispositivo a programar.

Figura 21. Configurando el programador a utilizar.

Capítulo 3. Desarrollo del sistema

Una vez establecido tanto el microcontrolador como el programador a utilizar,

se puede proceder a la programación del Bootloader (figura 22) y, una vez

completado el proceso, se podrá utilizar la capa de abstracción hardware de

Arduino para programar al sistema (figura 23).

Figura 22. Quemando el Bootloader en el sistema.

Figura 23. Carga de nuestro código en el sistema.

Capítulo 3. Desarrollo del sistema

### 3.3.2. Software

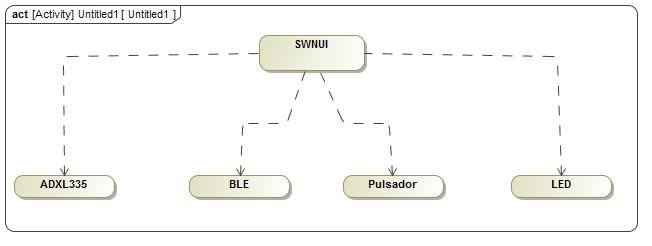
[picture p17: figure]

Figura 24. Clases y dependencias de nuestro sistema.

Buscando una estructura jerárquica del sistema, que nos permita ir

desarrollando las distintas partes del mismo y a su vez ir verificando su

funcionalidad, optamos por estructurar el código en distintas clases que

controlen a cada elemento distinguible del sistema por separado (led, pulsador,

módulo BLE y acelerómetro) y, una clase maestra (nuestro sistema completo,

SWNUI) que controle a su vez las clases anteriores. Con esto, conseguimos un

código organizado, al mismo tiempo que se enfoca al sistema como un “objeto

software” único y exportable, lo que simplifica su importación y reutilización en

distintos proyectos (a través de su librería). La estructura de las clases, así

como la dependencia entre ellas, pueden ser observadas en la figura 24.

Con esta estructura del código basada en clases y su utilización para el

desarrollo del “objeto software” diseñado que corresponde con nuestro sistema

físico real, estamos haciendo uso de la “esencia” o “filosofía” de la

programación orientada a objetos (POO). Este hecho, no solo especifica la

organización o el tipo de metodología de programación, sino que nos lleva a un

nivel un poco más alto en la programación del sistema.

La interacción entre las clases viene gobernada por la clase SWNUI, pasando

por la gestión de la pulsación del pulsador mediante la clase PULSADOR,

realizando la lectura de los datos del acelerómetro a través de la clase

ADXL335, controlando el encendido o apagado del LED con la clase LED y

enviando la información por puerto serie con la clase BLE.

Capítulo 3. Desarrollo del sistema

Llegados a este punto, a continuación se especificará la funcionalidad de cada

clase desarrollada y se explicarán brevemente los aspectos más significativos

de su implementación.

Clase ADXL335:

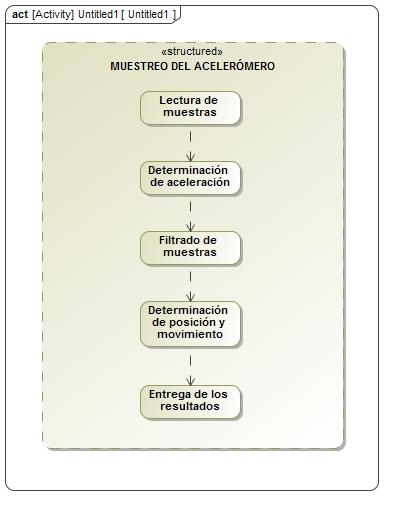
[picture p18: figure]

Figura 25. Diagrama de flujo del proceso de muestreo.

Esta clase cumple la función del manejo del acelerómetro. Incluye tanto la

configuración de los pines analógicos del microcontrolador como la lectura de

cada eje del acelerómetro así como el filtrado de las muestras obtenidas y la

determinación de los movimientos realizados y la posición del sistema.

La clase contiene un tipo de estructura (ADXL335_DATA) que almacena los

distintos valores obtenidos en el proceso de muestreo de los datos (valores de lectura, aceleraciones en m/s²
y en g, movimientos, posiciones y gestos).

Capítulo 3. Desarrollo del sistema

La lectura de los valores de aceleración de cada eje del acelerómetro se realiza

mediante el ADC (debido a la salida en tensión del acelerómetro analógico) y,

para conseguir un valor más fiable, se promedian las lecturas. Según la sensibilidad del sistema a ±3g se obtienen los valores de aceleración, en m/s² y

en g, de cada muestra.

Las muestras atraviesan un proceso de filtrado en el que se elimina el ruido de

la lectura (a través de umbrales que provocan cierta pérdida de precisión), se

corrige el efecto de la aceleración de la gravedad (gravedad terrestre de 1g) y

se elimina la captura consecutiva de muestras del mismo valor.

Pasado el proceso de filtrado, se procede a determinar el movimiento y la

posición del sistema correspondientes a las muestras de aceleración actuales,

finalizando el proceso de muestreo (figura 25) que comenzó con la lectura

analógica del sensor.

Los métodos más destacables para el uso de esta clase serían los siguientes:

- sampling(): El método principal que realiza todo el proceso descrito
anteriormente | (muestreo). | Correspondería | con | el | proceso | de

adquisición, filtrado y determinación del par movimiento/posición. El

método devuelve la estructura estándar de la clase que contiene todos

los valores adquiridos durante el proceso de muestreo.

- x(), y(), z(), ax(), ay(), az(), gx(), gy(), gz(), mx(), my(), mz(), pos(), mov():

Todos ellos son métodos de consulta por separado de los valores almacenados en la estructura estándar tras el proceso de muestreo. Útil

en el caso de que no se requiera extraer todos los datos de la

estructura.

Clase BLE:

La clase BLE se encarga del proceso de comunicación inalámbrica del sistema

a través del módulo BLE.

La clase configura la UART a utilizar y la velocidad en baudios que le

corresponderá (en este caso 9600 baudios) a dicho puerto serie.

Los métodos más importantes en esta clase serían:

- send(char c): El cual nos facilita el envío de bytes por el puerto serie.

Capítulo 3. Desarrollo del sistema

- print(String s): Método que permite el envío de cadenas de caracteres

(adecuado sobre todo para la depuración del sistema).

- println(String s): Otorga la misma funcionalidad que el método anterior

pero introduce un fin de línea en la cadena de caracteres enviada.

Clase Button:

En esta clase se establece la lectura del estado del pulsador, esto es, si se

encuentra presionado o no.

La clase se encarga de configurar el pin del microcontrolador correspondiente

al pulsador. Esto es, pin como entrada digital con la resistencia interna de “pull-

up” activada.

La rutina de tratamiento de interrupción (RTI) del pin correspondiente al

pulsador no se encuentra definida dentro de ninguna clase (ya que no es

posible definirla como método siendo de generación asíncrona). Dicha rutina se

establece como global en el interior del fichero de implementación (archivo

“.cpp”) de la clase SWNUI (a pesar de no formar parte de la misma).

Los únicos métodos de esta clase son:

- state(): Que nos devuelve el valor de entrada de lectura del pulsador.
- pressed(): Nos determina el estado del pulsador (si está presionado o

no).

Clase LED:

La clase LED se encarga de gestionar el encendido o apagado del LED

indicativo del sistema.

Al igual que la clase del pulsador, esta clase configura el pin del

microcontrolador correspondiente. Pin como salida digital.

Los métodos más significativos de la clase son:

- on(): Enciende el LED.
- off(): Apaga el LED.
- turn(): Conmuta el estado del LED.
- state(): Determina si el LED está encendido o apagado.

Capítulo 3. Desarrollo del sistema

- flash(unsigned long t): Hace parpadear al LED si ha transcurrido un

tiempo t desde su última llamada.

Clase SWNUI:

Es la clase principal de nuestro sistema, contiene la referencia al resto de

clases y éstas a su vez lo completan. Desde ella se tiene acceso a los

elementos controlados por el resto de clases, permitiéndonos el manejo total

de todos los dispositivos que conforman a nuestro sistema (microcontrolador,

LED, Pulsador, Acelerómetro y BLE). De modo que se podría decir que esta

clase es nuestro sistema.

Solucionados los mecanismos de muestreo de datos del acelerómetro, gestión

del pulsador y control del LED en el resto de clases, solo quedaría el desarrollo

del corazón de nuestro sistema, la funcionalidad del mismo.

Antes de entrar de lleno en el desarrollo de la funcionalidad, determinemos la

interacción que tendrá nuestro objeto SWNUI en el programa principal. Para no

perder la esencia de la programación orientada a objetos, se debe proceder a

implementar todo el comportamiento del sistema dentro de su clase, así, en el

programa principal exclusivamente debería existir una creación del objeto, una

llamada a su configuración inicial y un método de actualización de su

comportamiento (figura 26).

Figura 26. Programa principal.

Capítulo 3. Desarrollo del sistema

Recordemos que el sistema deberá tener dos modos de funcionamiento, uno

continuo y otro discreto, y se podrá conmutar entre ambos modos mediante la

doble pulsación del pulsador. Teniendo eso en mente procedemos a programar

dicha funcionalidad.

Inicialmente, correspondiente al método init(), la clase fija los valores iniciales

de todas sus variables (entre ellas el modo inicial del sistema) e inicializa cada

uno de sus objetos además de configurar el modo de bajo consumo y

establecer la interrupción del pulsador (figura 27).

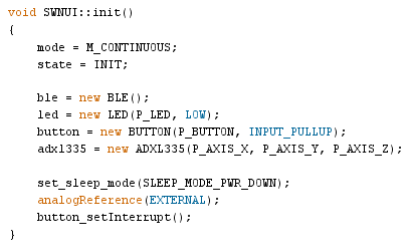
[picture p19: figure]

Figura 27. Método init().

Posteriormente a su inicio, en el método correspondiente a la actualización de

su comportamiento, el método update(), el sistema entra en un bucle infinito en

el que lo primero que hace es determinar el modo de funcionamiento a ejecutar

según en el que se encuentre (figura 28).

Figura 28. Método update().

Capítulo 3. Desarrollo del sistema

El “modo continuo” del sistema (figura 29) comprueba si ha existido una doble

pulsación (entrada doble en la rutina de tratamiento de interrupción del

pulsador en un tiempo inferior a un segundo) para el cambio de modo y en tal

caso lo realiza (método changeMode_management()). En caso de que no se

cambie de modo, se obtienen los datos correspondientes al muestreo del

acelerómetro y se procede al envío de los datos correspondientes al

movimiento en algún eje. Se hace parpadear al led a 1 Hz para indicarnos que

se encuentra en el “modo continuo” y se espera un tiempo de muestreo (30

Hz).

Figura 29. Modo continuo.

El “modo gestos” del sistema es algo más complejo, dado que la funcionalidad

tiene pasos vienen definidos, se procede a desarrollar una máquina de estados

que gestione cada parte del proceso. El diagrama de estados de dicha

máquina es el mostrado en la siguiente imagen (figura 30):

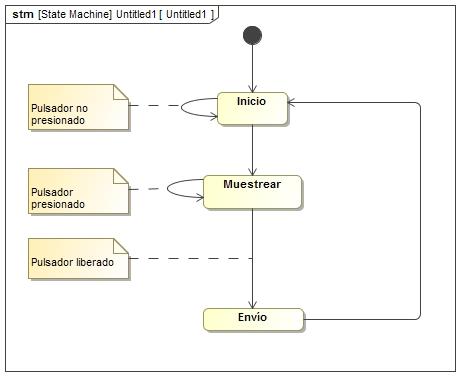
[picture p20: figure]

Figura 30. Máquina de estados del modo gestos.

Capítulo 3. Desarrollo del sistema

La implementación de la máquina de estados en el código del programa se

basa en la sentencia switch (figura 31). En el estado inicial, el sistema entra en

bajo consumo hasta que el usuario presione el pulsador. Una vez despierto, el

sistema espera un tiempo prudencial para permitir el cambio de modo (la

segunda pulsación) y, al igual que en el modo continuo, se gestiona la

posibilidad del cambio de modo. En caso de que no se produzca el cambio, el

sistema pasará al estado de muestreo en el que, mientras se mantenga el

pulsador presionado se irán almacenando en arrays los movimientos y

posiciones que conformarán el gesto. Una vez soltado el pulsador, entraremos

en el estado de envío en donde se determinará si el gesto corresponde a

alguno predefinido y en tal caso se enviará el comando asociado.

Figura 31. Modo gestos.

Capítulo 3. Desarrollo del sistema

Con esto, tendríamos a grandes rasgos, el desarrollo del software que

determina la funcionalidad que debe de tener nuestro sistema según las

especificaciones del mismo. La finalización del software cubre otro de los

pilares fundamentales en el proceso de desarrollo definitivo del prototipo que

estamos elaborando y nos acerca un poco más hacia nuestra meta.

## 3.4. Desarrollo del modelo 3D de la carcasa

De forma complementaria al desarrollo hardware/software y aunque ya

tenemos un prototipo funcional del sistema, parte del objetivo del sistema es

ser un dispositivo “vestible” (portable en la mano) y, por tanto, nuestro prototipo

no estaría completo hasta comprobar el correcto cumplimiento del requisito de

diseño wearable. En este apartado, se procede a diseñar y desarrollar el

modelo 3D de la carcasa del sistema (parte física/mecánica del sistema).

El software utilizado para el diseño CAD es Freecad, software que, como su

propio nombre indica, es gratuito, además de open source. El proceso de

diseño se basa en la creación de piezas aisladas para, posteriormente,

fusionarlas entre sí hasta obtener el objeto completo.

A continuación se muestra el proceso de creación del objeto completo

mediante la creación de cada pieza separada y la unión de estas (figura 32):

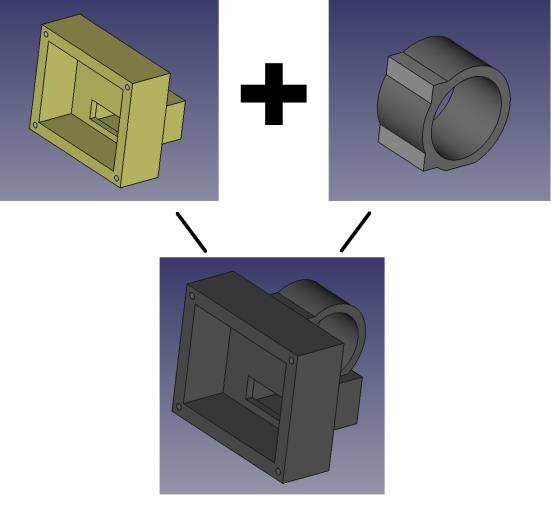
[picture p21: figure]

Figura 32. Piezas del SWNUI en el Freecad.

Capítulo 3. Desarrollo del sistema

Por otro lado, se crea la tapa de la carcasa, la cual debe presentar los orificios

adecuados en las posiciones requeridas para que los elementos de la placa

sean accesibles. Así, los huecos corresponderán al pulsador, el LED y el

conector ICSP de la PCI (figura 33).

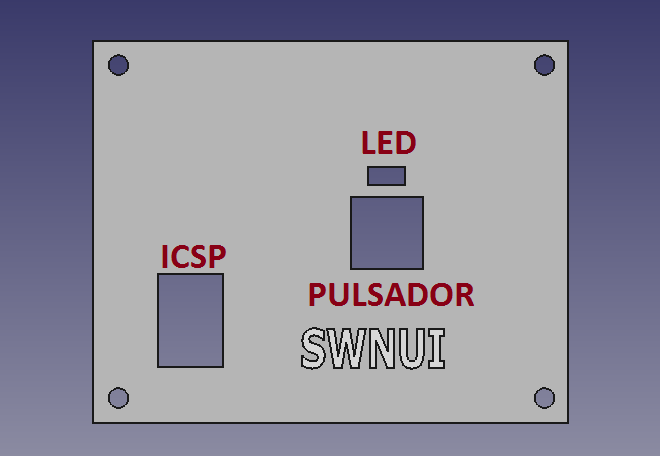
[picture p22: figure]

Figura 33. Tapa de la carcasa en Freecad.

Una vez que tenemos el diseño completo (figura 34), procedemos a exportar

tanto la tapa como el resto de la carcasa en archivos “.obj” para su envío a

fabricación (a partir de una impresora 3D).

Figura 34. Diseño completo de la carcasa en Freecad.

Terminada la impresión de la pieza, obtenemos un buen resultado en el modelo

realizado (figura 35). Los taladros correspondientes a los tornillos de sujeción

Capítulo 3. Desarrollo del sistema

de la tapa tuvieron que ser repasados con una pequeña broca para eliminar

impurezas que quedaron tras el proceso de fabricación.

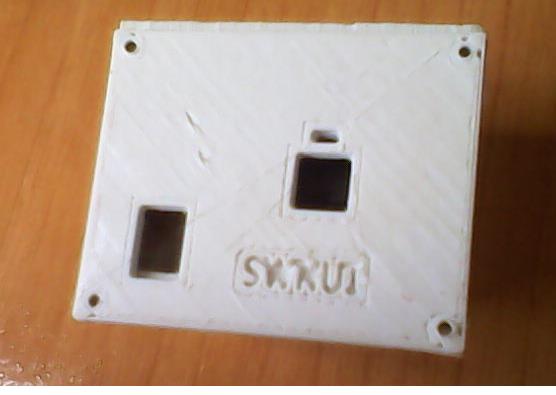
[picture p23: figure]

Figura 35. Carcasa impresa del SWNUI.

Una vez finalizado el desarrollo de la carcasa, solo restaría el ensamblaje del

sistema dentro de la misma y su puesta en marcha.

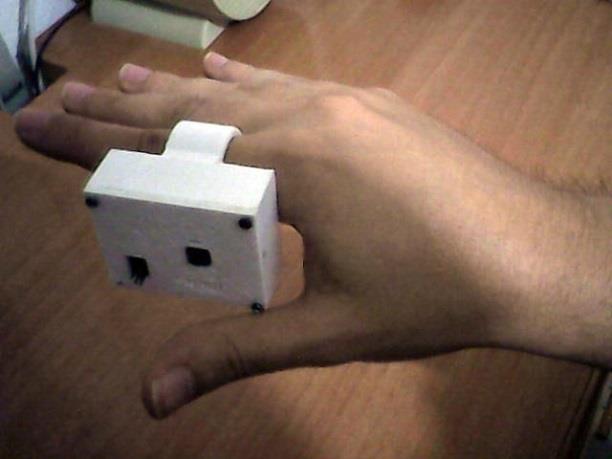
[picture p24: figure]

Figura 36. SWNUI completo.

Capítulo 3. Desarrollo del sistema

Como puede observarse en la imagen anterior (figura 36), a pesar de su tosco tamaño debido a las limitaciones de las herramientas de fabricación (soldadura realizada a mano) y del hecho de que lo que se ha desarrollado es un prototipo, podemos concluir que el sistema cumple las características de un dispositivo “vestible”, que era una de las especificaciones iniciales impuestas en nuestro sistema.

Capítulo 3. Desarrollo del sistema

# Capítulo 4. Verificación y pruebas

El prototipo (SWNUI), desarrollado en el apartado anterior, tiene como finalidad

permitir la interacción de un usuario con diferentes agentes o sistemas externos

que presenten una interfaz compatible con el tipo de interacción que nos

permite nuestro sistema. Esto implicaría la estandarización de los elementos a

controlar para que sean capaces de reconocer las peticiones demandadas por

la persona a través de los gestos realizados o, la modificación de estos

elementos para añadirles esa compatibilidad hacia nuestro sistema.

En este apartado verificaremos el correcto funcionamiento de los dos modos de

operación del SWNUI mediante el control de un PC. Para ello, se procederá a

adaptar al mismo para que sea capaz de reconocer lo que el SWNUI transmite.

Como se verá, esta adaptación no requiere de ninguna modificación en el

hardware o software del PC ya que, todo ordenador presenta entradas USB.

## 4.1. Sistema de pruebas

Los ordenadores son quizás, las computadoras más genéricas existentes hasta

el momento, su control se basa, sobre todo, en dos periféricos bien

reconocidos: el ratón y el teclado. Ambos periféricos se conectan al PC

mediante el bus serie universal (USB) y mediante un driver específico es

reconocido por el ordenador como dispositivo de entrada.

Pues bien, nuestro sistema de prueba se basará en la creación de un elemento

que actúe como periférico de entrada del ordenador a través de USB,

simulando ser un ratón o un teclado. Para ello, recurriremos a un sistema

desarrollado por Digistump denominado Digispark (figura 37), el cual no es más

Capítulo 4. Verificación y pruebas

que un microcontrolador attiny85 de Atmel que, a pesar de que no lleva

implementado USB nativo, hace uso del firmware V-USB de Atmel para

implementar vía software un controlador USB dentro de la misma unidad. Esto

permite al microcontrolador ser reconocido por el ordenador como un

dispositivo HID-USB (Human Interface Device USB) genérico. Los dispositivos

HID-USB genéricos son reconocidos por la computadora gracias a un driver

que viene integro en la mayoría de sistemas operativos (Windows, Unix,

Android, etc.) y que permite detectar al periférico como dispositivo de interfaz

humana: ratón, teclado, gamepad…

Figura 37. Digispark.

Podríamos conseguir el mismo resultado a partir de cualquier sistema que se

conectará por el puerto USB y lo convirtiera a éste en un puerto serie virtual por

el que enviar la información, pero esto requeriría de algún software en la

computadora que se debiera ejecutar cada vez que el dispositivo se conectara,

o que corriera en segundo plano ocupando memoria del sistema. El uso del

Digispark nos permite crear un enlace que convierte al SWNUI en un auténtico

periférico de ordenador, reconocible de forma automática en cuanto se

conectara al mismo.

Por tanto, el sistema de prueba lo conformará el Digispark junto con un módulo

BLE, que permita recibir los datos del SWNUI e interpretarlos para el control del

ratón/teclado. Así, el sistema completo vendría dado como se muestra en la

figura 38.

Capítulo 4. Verificación y pruebas


Figura 38. Sistema de verificación completo.

El Digispark es un sistema desarrollado posteriormente a la plataforma Arduino

y que buscaba ser una solución de menor tamaño y precio, compatible con

toda la capa de abstracción hardware creada para Arduino, y que otorgaba esa

gran simplicidad a la hora de desarrollar aplicaciones. Por este motivo, el

Digispark es un sistema que se programa con la misma filosofía que un Arduino

y por ello, el software de programación no es otro que el IDE de Arduino, pero

previamente | debemos | configurarlo | para | añadirle | los | componentes

correspondientes a la programación del Digispark (archivos, “cores” y

compilador).

El proceso de inserción de los componentes correspondientes al Digispark en

el entorno de programación de Arduino se basa en la descarga de la carpeta

“digistump” desde la web: https://github.com/digistump/DigistumpArduino y su

inclusión dentro de la subcarpeta “hardware” del directorio raíz de Arduino

(C:/…/Arduino.X.X.X/hardware”). Esto otorga al IDE la capacidad de

seleccionar como plataforma de programación las diversas placas de

Digistump, entre ellas la Digispark, e inserta el compilador específico de esta

plataforma (Micronucleus).

El microcontrolador que compone al Digispark presenta poca capacidad en

memoria, pero es más que suficiente para cumplir con nuestro propósito. A

pesar de ello, algo esencial que nos faltaría en el Digispark sería un puerto

serie (el attiny85 no posee UART) para comunicarnos con el módulo BLE. Una

Capítulo 4. Verificación y pruebas

solución a esto es implementar una UART virtual dentro del microcontrolador,

de modo que recurrimos al uso de la librería SoftSerial (Software Serial)

diseñada para el Digispark. Esta librería nos permite crear un puerto serie en

los pines compatibles, en nuestro caso los pines P0 (Rx) y P1 (Tx).

Figura 39. Error de definición múltiple del __vector_2.

La inserción de la nueva librería SoftSerial junto al uso de las librerías

correspondientes a la creación y manejo del periférico USB (DigiUSB) plantea

un nuevo problema ya que, aunque por separado las dos librerías funcionan de

forma adecuada, el uso de ambas al mismo tiempo genera un error en la etapa

de compilación por definición múltiple del “__vector_2”, correspondiente al

vector de “Pin Change interrupt” del pin PCINT0 (figura 39). Esto se debe a

que, por un lado, la librería SoftSerial hace uso del mismo para la detección de

datos entrantes por el pin Rx del puerto serie creado, mientras que la librería

DigiUSB, a pesar de que no utiliza exactamente ese pin para el puerto USB,

presenta una definición genérica de las interrupciones “Pin Change” dentro del

archivo de configuración del dispositivo USB “usbconfig.h”.

Capítulo 4. Verificación y pruebas

La solución a este problema pasa por identificar la definición genérica de las

interrupciones de “Pin Change” para el USB en el archivo “usbconfig.h”

correspondiente a cada librería de manejo del ratón y el teclado (Digimouse y

Digikeyboard) y modificarla para que se utilice la interrupción hardware INT0

(correspondiente al pin P2 del Digispark) en vez de la PCINT0.

El archivo “usbconfig.h” se puede encontrar dentro de las carpetas

DigisparkMouse | y | DigisparkKeyboard | en | la | ruta: | “…/Arduino-

X.X.X/hardware/digistump/avr/libraries”. El código que nos interesa se localiza

entre las líneas 378 y 384 del archivo (figura 40) y debe modificarse tal y como

se muestra en la figura 41.


Figura 40. Código de definición de las interrupciones en usbconfig.h.


Figura 41. Código modificado de definición de la interrupción INT0 en usbconfig.h.

Modificar la librería de tal forma puede no resultar la solución más elegante,

además, se pierde el pin P2 del Digispark, pues este es el correspondiente a la

interrupción INT0 que hemos establecido como interrupción de la línea USB+ y,

por ende, debe de cortocircuitarse con el pin correspondiente (P3).

Capítulo 4. Verificación y pruebas

De este modo, la conexión del Digispark con el módulo BLE vendrá dada de la

forma en que se muestra en la figura 42.

Figura 42. Código modificado de definición de la interrupción INT0 en usbconfig.h.

Para el proceso de conexión de los elementos que conforman al sistema de

pruebas, se procede mediante la utilización de una placa de baquelita

perforada, en la cual se suelda los conectores apropiados y se realizan las

conexiones pertinentes de los dos elementos. Quedando el sistema de pruebas

como se muestra en la figura 43.


Figura 43. Sistema de pruebas. Periférico receptor del SWNUI.

Realizado todo lo anterior, tendríamos al sistema de pruebas disponible para la

creación del software necesario para la recepción e interpretación de los datos

comunicados por el SWNUI.

Capítulo 4. Verificación y pruebas

## 4.2. Pruebas realizadas

### 4.2.1. Pruebas de funcionalidad

Para comprobar la adecuada funcionalidad del SWNUI, procederemos a

controlar un ordenador con sistema operativo Windows 7. Para ello,

realizaremos dos tipos de controles. Por un lado, procederemos a implementar

el control del cursor de la computadora con el fin de corroborar la correcta

operación del “Modo continuo” del sistema, permitiendo desplazar al cursor por

la pantalla y gestionar el click izquierdo. Por otra parte, implementaremos el

control del programa Power Point de Microsoft Office permitiéndonos navegar

entre las diapositivas y entrar y salir del modo presentación, esto lo haremos

configurando al periférico como si fuera un teclado y, nos ofrecerá la

oportunidad de comprobar el correcto funcionamiento del “Modo gestos” del

sistema.

Prueba del “Modo continuo”: SWNUI como cursor del ordenador

En la prueba de verificación del “modo continuo”, el Digispark es conectado al

ordenador. Pasado un cierto tiempo de inicialización, es reconocido como ratón

HID-USB y comienza a buscar e intentar conectarse al SWNUI. Una vez

conectado, se verifica que la inclinación del SWNUI en cada una de las

direcciones produce el desplazamiento del cursor en pantalla, así como que se

genera el Click en el momento en que se desplaza la mano en dirección al

suelo.

Posición estándar

(El cursor no se

desplaza)

Inclinación derecha

(El cursor se desplaza

hacia la derecha)

Inclinación izquierda

(El cursor se desplaza

hacia la izquierda)

Capítulo 4. Verificación y pruebas

El código presente en el Digispark para controlar el movimiento del cursor del

ordenador se corresponde al diagrama de actividad siguiente (figura 44).


Figura 44. Diagrama de actividad del control del cursor.

A continuación, procedemos a definir la utilidad de cada bloque funcional:

- Inicializar Datos: Establece los valores iniciales de las variables del

sistema.

- Inicializar Ratón: Establece la conexión USB con el ordenador como

ratón HID.

Inclinación arriba

(El cursor se desplaza

hacia arriba)

Inclinación abajo

(El cursor se desplaza

hacia abajo)

Capítulo 4. Verificación y pruebas

- Conectar con SWNUI: Se conecta a través del módulo BLE con el

SWNUI.

- Datos disponibles: Determina la existencia de bytes disponibles en el

“buffer” del puerto serie (datos transmitidos por el SWNUI).

- Leer datos: Lee y almacena en variables los datos obtenidos por el

puerto serie.

- Determinar movimiento cursor: Determina la dirección y velocidad de

movimiento del cursor a partir de los datos obtenidos.

- Determinar click del cursor: Determina si ha de producirse un click.
- Actualizar cursor: Mantiene con vida la conexión USB y actualiza el

estado (movimiento y click) del cursor.

Prueba del “Modo gestos”: SWNUI como teclado del ordenador

En la prueba de verificación del “modo gestos”, el Digispark es conectado al

ordenador. Pasado un cierto tiempo de inicialización, es reconocido como

teclado HID-USB y comienza a buscar e intentar conectarse al SWNUI. Una

vez conectado, se verifica en principio que, ningún movimiento del SWNUI es

reconocido por el ordenador mientras el pulsador no se encuentre presionado.

Procediendo como se especifica en el “modo gestos”, se presiona el pulsador y

se realizan los conjuntos de movimientos preestablecidos que componen a los

diversos gestos, al dejar de presionar el pulsador se puede comprobar como

cada uno de estos gestos es reconocido por el ordenador de forma correcta.

Cada gesto es asociado, en el código del Digispark, a una tecla del teclado

adecuada para controlar la presentación de Power Point en su totalidad. De

este modo, esta asociación viene a ser como sigue:

Gesto | Tecla | Función
Next | KEY_ARROW_RIGHT | Siguiente diapositiva
Prev | KEY_ARROW_LEFT | Anterior diapositiva
OK | F5 | Modo presentación
CANCEL | ESC | Salir presentación

Capítulo 4. Verificación y pruebas

El código albergado por el Digispark que permite controlar la pulsación de

teclas del ordenador se corresponde al siguiente diagrama de actividad (figura

45).

Figura 45. Diagrama de actividad del control del teclado.

De modo que la utilidad de cada bloque funcional sería:

- Inicializar Datos: Establece los valores iniciales de las variables del

sistema.

- Inicializar Teclado: Establece la conexión USB con el ordenador como

teclado HID.

- Conectar con SWNUI: Se conecta a través del módulo BLE con el

SWNUI.

- Datos disponibles: Determina la existencia de bytes disponibles en el

“buffer” del puerto serie (datos transmitidos por el SWNUI).

- Leer datos: Lee y almacena en variables los datos obtenidos por el

puerto serie.

- Determinar tecla: Determina la tecla correspondiente al gesto recibido.
- Realizar | pulsación | tecla: | Genera | la | pulsación | de | la | tecla

correspondiente.

- Actualizar teclado: Mantiene con vida la conexión USB.

Capítulo 4. Verificación y pruebas

Prueba de cambio de modo

La conmutación entre los dos modos de funcionamiento se realiza mediante la

doble pulsación del pulsador del SWNUI en un periodo inferior a un segundo.

Procedemos a realizar dicha operación tanto desde el “modo continuo” como

desde el “modo gestos”, consiguiéndose lo deseado (la conmutación) en

ambos modos. No obstante, se observa que la conmutación hacia el “modo

continuo” desde el “modo gestos” genera una mayor dificultad debido al estado

de bajo consumo del cual ha de despertarse el sistema previamente a la

gestión del cambio de modo.

### 4.2.2. Pruebas de prestaciones

Prueba de diseño wearable

Con un calibre se procede a examinar las dimensiones de la carcasa diseñada

y que contiene al SWNUI. El resultado dado corrobora que el diseño no supera

las dimensiones de 5 cm en cualquier dirección del espacio.

A pesar de su tosco tamaño, se aprecia que el diseño “prototipado” se adecua

a la portabilidad del mismo por parte del usuario, consigue no ser demasiado

pesado y no suele entorpecer los movimientos del portador.

Prueba de indicación de modo

De manera visual se puede apreciar como el LED indicativo del sistema

SWNUI parpadea con una frecuencia de 1 Hz mientras el modo de

funcionamiento es el continuo y que, al conmutar de modo, el LED pasa a un

estado apagado mientras se esté en el bajo consumo del “modo gestos”. El

LED pasa a encenderse en el momento en el que se presiona el pulsador para

realizar el conjunto de movimientos que determinan un gesto y, el LED vuelve a

apagarse en cuanto se suelta el pulsador (entrando nuevamente en bajo

consumo).

Capítulo 4. Verificación y pruebas

### 4.2.3. Tabla resumen de pruebas

Nº

Nombre o ID del

requisito

Descripción de la prueba | Resultado
1 | Función del sistema | Verificado mediante pruebas de funcionalidad | Favorable
2 | Comunicación
| inalámbrica | Verificado mediante pruebas de funcionalidad | Favorable
3 | Conexión automática | Verificado mediante pruebas de funcionalidad | Favorable
4 | Modo continuo | Verificado por prueba de funcionalidad de modo
| | continuo | Favorable

5

Modo gestos | Verificado por prueba de funcionalidad del modo
| gestos

Favorable

6

Cambio de modo | Verificado por prueba de funcionalidad de cambio
| de modo

Favorable

7

Diseño Wearable | Verificado por prueba de prestación de diseño
| wearable

Favorable

8

Indicación de modo | Verificado por prueba de prestación de indicación
| de modo

Favorable

Tabla 4.2.3.1 Tabla de las pruebas realizadas

# Capítulo 5. Manual de instalación y uso

## 5.1. Manual de instalación

El SWNUI es un sistema portable diseñado para su colocación en el dedo

índice del usuario (figura 46) y, el dedo pulgar permitirá la pulsación del

pulsador.


Figura 46. Instalación del SWNUI en la mano.

Para la comunicación inalámbrica el sistema utiliza Bluetooth Low Energy, con

las limitaciones de distancia que ésta conlleva. La distancia adecuada para que

el SWNUI pueda conectarse e interactuar con los sistemas externos debe de

ser inferior a los 10 metros.

Respecto a los sistemas externos a los que se conectará el SWNUI, estos

tendrán que presentar la interfaz de conexión e interpretación de los gestos, así

como un menú, adecuado al SWNUI.

Capítulo 5. Manual de instalación y uso

## 5.2. Manual de uso

### 5.2.1. Configuración inicial

Para comenzar, el SWNUI se deberá posicionar de forma correcta en el dedo

del usuario (véase el apartado anterior, de instalación). Inicialmente, se

encontrará en el modo de funcionamiento correspondiente al envío de gestos

de forma aislada, el “modo gestos”, y no se requiere de ninguna configuración

extra para comenzar a utilizarlo.

### 5.2.2. Conexión con el sistema a controlar

El SWNUI es un sistema simple por definición. Así, una vez se encuentre

dentro del rango de un sistema de control, se establecerá la conexión

inalámbrica de forma automática, sin que el usuario deba intervenir.

### 5.2.3. Cambio de modo

El modo de funcionamiento del SWNUI podrá conmutarse mediante la doble

pulsación del botón en un periodo inferior a un segundo.

### 5.2.4. Modo continuo

El manejo continuo del sistema no es exclusivamente simple, sino que también

es intuitivo. El usuario puede observar de forma directa (realimentación visual)

el resultado de su interacción con el sistema a controlar.

En el caso del control del cursor de un ordenador, la inclinación de la mano

determinará la dirección y velocidad de movimiento del mismo y un

desplazamiento rápido en la dirección del suelo cumplirá la función del click.

### 5.2.5. Modo gestos

El “modo gestos” es el modo estándar por defecto del SWNUI, a través del cual

el usuario puede interaccionar y controlar sistemas que requieran de acciones

específicas independientes del tiempo, como puede ser la navegación dentro

de un menú (avanzar, retroceder, aceptar, cancelar) de un sistema de consulta

Capítulo 5. Manual de instalación y uso

de información (Pantalla Informativa) o un terminal punto de venta PTV (por

ejemplo, equipos de venta de tickets en servicios de transporte, como el metro

o el autobús).

Para la realización de un gesto se procede de la siguiente forma:

1. Se posiciona la mano en la posición inicial del gesto.
2. Se presiona el pulsador (se inicia el proceso de muestreo).
3. Se realizan los movimientos e inclinaciones que componen al gesto.
4. Se suelta el pulsador (se finaliza el proceso de muestreo y, se determina

y envía el gesto correspondiente).

### 5.2.6. Consumo

El sistema entrará en un estado de bajo consumo, única y exclusivamente en el

“modo gestos”, por tanto se debe evitar la utilización del “modo continuo”

siempre y cuando no se requiera de su uso.

### 5.2.7. Movimientos y posiciones posibles

El SWNUI registra una gran variedad de posiciones y movimientos del mismo,

las cuales a su vez, componen los distintos gestos preestablecidos.

A continuación se recogen las diversas posiciones reconocibles por el sistema:

Posición boca-arriba | Posición derecha | Posición izquierda
Posición boca-abajo | Posición arriba | Posición abajo

Capítulo 5. Manual de instalación y uso

Por | otro | lado, | los | movimientos | reconocibles | serían, | obviamente:

Desplazamientos hacia la derecha, izquierda, arriba, abajo, adelante, atrás y el

no desplazarse.

### 5.2.8. Gestos predeterminados

El conjunto de varios movimientos e inclinaciones reconocibles por el sistema

(apartado anterior) pueden determinar uno de los gestos predefinidos en el

sistema.

Existen cuatro gestos predeterminados que corresponden al control de

interfaces del tipo: avanzar, retroceder, aceptar, cancelar.

A continuación se recopilan los movimientos y posiciones que componen a

cada uno de estos gestos:

Gesto Avanzar:

Gesto Retroceder:

1 - Posición estándar | 2 - Posición derecha
1 - Posición derecha | 2 - Posición estándar

Capítulo 5. Manual de instalación y uso

Gesto Aceptar:

Gesto Cancelar:

Como puede observarse, estos gestos predeterminados son conformados exclusivamente por posiciones de la mano con el fin de simplificar al máximo el movimiento que deba realizar el usuario.

1 - Posición estándar | 2 - Posición derecha | 3 - Posición abajo
1 - Posición abajo | 2 - Posición derecha | 3 - Posición estándar

Capítulo 5. Manual de instalación y uso

# Capítulo 6. Conclusiones y trabajo futuro

Dentro del ámbito de los sistemas de interacción natural de usuario no ópticos, el prototipo del sistema desarrollado en este TFG nos ha permitido considerar diferentes posibilidades de interacción basada en gestos, con las diversas interfaces de usuario que se presentan hoy en día en la multitud de tecnologías cotidianas que nos rodean.

El objetivo del proyecto realizado nos ha llevado a ahondar en los diferentes sensores de medición inercial basados en tecnología MEM, con el fin de determinar qué sensor sería el más apropiado para nuestra aplicación según los requerimientos de nuestro sistema y el realizar el apropiado procesado de los datos obtenidos del mismo. Y de esta forma, acabamos determinando que exclusivamente con un acelerómetro podríamos alcanzar nuestro objetivo. Por otro lado, la necesidad de comunicación inalámbrica nos permitió profundizar en el uso de la tecnología Bluetooth Low Energy y aprendimos ciertas características técnicas al respecto (como es la ventaja del poco consumo, así como la limitación en velocidad con respecto al protocolo Bluetooth estándar).

El hecho de afrontar el proceso de creación de un prototipo para nuestro sistema, nos ha permitido abordar todos los pasos que definen la fabricación de un sistema electrónico completo, pasando por el desarrollo hardware y software, y acabando con la creación de su carcasa (desarrollo mecánico). Todo ello nos ha posibilitado aprender el manejo de los software de diseño asistido por computadora Eagle y Freecad, y hemos aprendido a exportar los archivos necesarios tanto para la fabricación de la placa de circuito impreso (ficheros Gerbers y Excellons), como para el diseño 3D de la carcasa (archivos .obj).

Evidentemente, transformar el sistema en producto desde el prototipo que es, llevaría a priorizar una mejora en la parte mecánica del mismo, buscando una

Capítulo 6. Conclusiones y trabajo futuro

reducción mucho mayor del tamaño y el peso así como incrementar la robustez física del sistema.

El sistema elaborado cumple con su función, no obstante, presenta ciertas limitaciones a la hora de determinar los gestos (entre otros, gestos complicados pueden no ser apropiadamente reconocibles y puede producirse confusión entre gestos). Un sensor de bajas prestaciones como el acelerómetro utilizado presenta una gran cantidad de ruido que debería, más que ser filtrado (como hemos hecho), ser tratado y compensado mediante la inserción de algún otro elemento sensor de movimiento, como un giroscopio, con el fin de eliminar posibles errores en las muestras obtenidas al mismo tiempo que se aumenta la precisión y sensibilidad de las mismas, consiguiendo así, unos gestos reconocibles mucho más sofisticados. La inserción del nuevo componente hardware y su aplicación para la determinación de gestos mejorados, nos llevaría a la implementación software de ciertos algoritmos que permitan la detección, más profunda, de los nuevos gestos más complejos. Respecto a lo anterior, se ha de tener presente, que la mejora del sistema en esta dirección debe seguir la filosofía original del proyecto en cuanto a su simplicidad para el usuario.

# Apéndice A. Presupuesto de elaboración

Componente | Coste unitario (€)

Unidades

empleadas

Coste total (€)

ATMEGA328P | 1.59 € | 1 | 1.59 €
ADXL335 | 1.68 € | 1 | 1.68 €
BLE CC2541 Bolutek Module | 4.19 € | 1 | 4.19 €
Push button | 0.055 € | 1 | 0.06 €
Led SMD | 0.05 € | 1 | 0.05 €
Resistencia SMD | 0.0242€ | 2 | 0.05 €
Condensador SMD | 0.05 € | 2 | 0.1 €
Pin headers | 0.0355 € | 13 | 0.47 €
Baterías (pilas AAA) | 1.125 € | 2 | 2.25 €
PCB | 1.25 € | 1 | 1.25 €
Diseño 3D | 4.78 € | 1 | 4.78 €
Estaño | 0.90 € | 1 | 0.90 €
| | Total | 17.37 €

Tabla en Apéndice A.1. Coste de componentes y material fungible

Apéndice A. Presupuesto de elaboración

Equipo/software

Coste

unitario (€)

Periodo de

amortización

| | | Periodo de uso | Coste total (€)
Ordenador Portatil | 79.83 € | 4 meses | 4 meses | 79.83 €
Eagle Hobbyist | 23.33 € | 4 meses | 4 meses | 23.33 €
Arduino IDE | 0 € | 4 meses | 4 meses | 0 €
Freecad | 0 € | 4 meses | 4 meses | 0 €
| | | Total | 103.17 €
| | Tabla A.2

Tabla en Apéndice A.2. Amortización de equipos y licencias de software

Actividad | Horas
Coordinación del TFG | 15
Análisis de requisitos | 20
Desarrollo hardware/software del prototipo | 150
Realización de las pruebas | 20
Redacción de la memoria | 49
Preparación de la presentación | 25
| | Horas totales | 279
Coste por hora | 7 € | Coste total de la mano de obra | 1953 €

Tabla en Apéndice A.3. Horas invertidas en la realización del proyecto (mano de obra)

Concepto | Coste (€)
Coste de componentes y material fungible | 17.37 €
Amortización de equipos y licencias de software | 103.17 €
Mano de obra | 1953 €
Coste total | 2073.54 €

Tabla en Apéndice A.3. Presupuesto total

# Referencias

[1] R. Birwhistell, Introduction to kinesics, Lousville: University of Louisville,

1952.

[2] Microsoft, «microsoft,» Microsoft, 4 11 2010. [En línea]. Available:

http://www.microsoft.com/en-us/news/press/2010/nov10/11-04kinectlaunchpr.aspx. [Último acceso: 21 11 2013].

[3] Microsoft, «xbox,» Microsoft, [En línea]. Available: http://www.xbox.com/es-ES/Kinect. [Último acceso: 19 11 2013].
[4] Guinness World Records, «guinnessworldrecords,» Guinness World
Records, | 28 | 11 | 2000. | [En | línea]. | Available:

http://www.guinnessworldrecords.com/records-9000/fastest-selling-gaming-peripheral/. [Último acceso: 21 11 2013].

[5] Nintendo, | «nintendo,» | Nintendo, | [En | línea]. | Available:
http://www.nintendo.com/wii/what-is-wii/#/controls. [Último acceso: 19 11

2013].

[6] Play Station, «playstation,» Play Station, 17 09 2010. [En línea]. Available: http://es.playstation.com/psmove/. [Último acceso: 2013 11 21].
[7] El mundo, «elmundo,» El mundo, 30 11 2006. [En línea]. Available:

http://www.elmundo.es/navegante/2006/11/29/juegos/1164803253.html. [Último acceso: 21 11 2013].

[8] Periodico 20 minutos, «20minutos,» Periodico 20 minutos, 10 09 2007. [En
línea]. | | | | | | Available:

Referencias

http://www.20minutos.es/noticia/273750/0/robot/operacion/haya/. [Último

acceso: 11 21 2013].

[9] J. M. y. J. P. F. Brunetti, «Comité Español de Automática,» 7 Septiembre
2007. | [En | | línea]. | | Available:

http://www.ceautomatica.es/old/actividades/jornadas/XXVIII/documentos/21 81-brunetti.pdf. [Último acceso: 09 Junio 2015].

[10

]

Energizer, | «Energizer,» | [En | línea]. | Available:
http://data.energizer.com/PDFs/E92.pdf. [Último acceso: 08 06 2015].

[11

]

Sparkfun, | «Sparkfun,» | 2009. | [En | línea]. | Available:

https://www.sparkfun.com/datasheets/Components/SMD/adxl335.pdf. [Último acceso: 08 06 2015].

[12

]

Bolutek, | «Banggood,» | [En | línea]. | Available:

http://img.banggood.com/file/products/20150104013145BLE-CC41-A%20Spefication.pdf. [Último acceso: 08 06 2015].

[13

]

T. Instrument, «Texas Instrument,» 2012. [En línea]. Available:

http://www.ti.com/lit/ds/symlink/cc2541.pdf.

[14

]

Atmel, | «Atmel,» | 2014. | [En | línea]. | Available:

http://www.atmel.com/images/Atmel-8271-8-bit-AVR-Microcontroller-

ATmega48A-48PA-88A-88PA-168A-168PA-328-

328P_datasheet_Complete.pdf.

[15

]

Arduino, | «Arduino,» | [En | | línea]. | Available:

http://www.arduino.cc/en/Main/ArduinoBoardUno.

[16

]

Eagle, «CadSoftUsa,» [En línea]. Available: http://www.cadsoftusa.com/. [Último acceso: 08 06 2015].

[17

]

Jmoon, | «Jmoon,» | [En | | línea]. | Available:
http://wiki.jmoon.co/programmers/usbasp/. [Último acceso: 08 06 2015].

Referencias

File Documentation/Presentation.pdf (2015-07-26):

Sistema de reconocimiento gestual

Sistema de reconocimiento

gestual

## Trabajo Fin de Grado

Realizado por: José Miguel Ríos Rubio Dirigido por: Francisco Javier Vizcaíno Martín

Departamento de Tecnología Electrónica - UNIVERSIDAD DE MALAGA Málaga, 16 de julio de 2015

## Sumario

### 1. Introducción 2. Objetivo del TFG 3. Especificaciones del sistema 4. Funcionalidad del sistema 5. Hardware 6. Software 7. Modelo 3D 8. Verificación y demostración 9. Conclusiones y líneas futuras

## Introducción


Lenguaje vs gestos

## Introducción

Gestos

## Introducción

- Interfaz de manejo de TPVs y sistemas informativos
- Interfaz de interacción para videojuegos
- Interfaz de control de robots (por ejemplo drones)
- Muchos otros…

Ámbitos de aplicación

## Introducción

Tecnologías de reconocimiento de gestos

Clasificación genérica:

- Tecnologías de reconocimiento óptico: Basadas en cámaras
- Tecnologías de reconocimiento no óptico:
Basadas en “sensores espaciales”: acelerómetros, giroscopios, magnetómetros o la combinación de algunos de estos elementos (IMUs)

## Introducción

Sistemas de reconocimiento de gestos en la actualidad

- Sistemas ópticos (Cámaras) • Sistemas no ópticos (IMUs)


## Introducción

Otro sistema novedoso de reconocimiento de gestos


Microchip MGC3130

Variación de campo electromagnético

## Sumario

### 1. Introducción 2. Objetivo del TFG 3. Especificaciones del sistema 4. Funcionalidad del sistema 5. Hardware 6. Software 7. Modelo 3D 8. Verificación y demostración 9. Conclusiones y líneas futuras

## Objetivo del TFG


## Simple Wireless Natural User Interface

## (SWNUI)

## Sumario

### 1. Introducción 2. Objetivo del TFG 3. Especificaciones del sistema 4. Funcionalidad del sistema 5. Hardware 6. Software 7. Modelo 3D 8. Verificación y demostración 9. Conclusiones y líneas futuras

## Especificaciones del sistema


• Determinación de gestos simples sin necesidad
de visión directa con el sistema a controlar
(Acelerómetro y microcontrolador)

• Bajo consumo y buena autonomía

• Comunicación inalámbrica (Bluetooth Low Energy)

• Modo continuo y discreto (Botón)

• Indicador de modo (LED)

• Diseño físico portable, “vestible” y confortable.

• Otros: Conexión automática, rango de alcance…

## Sumario

### 1. Introducción 2. Objetivo del TFG 3. Especificaciones del sistema 4. Funcionalidad del sistema 5. Hardware 6. Software 7. Modelo 3D 8. Verificación y demostración 9. Conclusiones y líneas futuras

## Funcionalidad del sistema

- Reconocimiento de posiciones y movimientos de la mano
- Manejo de sistemas externos: De interacción continua o interacción discreta.
- Modo Continuo (Streaming de datos)
- Modo Discreto (Modo “Gestos”)
- Pulsador del sistema
- LED del sistema

## Sumario

### 1. Introducción 2. Objetivo del TFG 3. Especificaciones del sistema 4. Funcionalidad del sistema 5. Hardware 6. Software 7. Modelo 3D 8. Verificación y demostración 9. Conclusiones y líneas futuras

## Hardware

Circuito eléctrico


## Hardware

Placa de circuito impreso: Diseño CAD


## Hardware

Placa de circuito impreso: Hardware final


## Sumario

### 1. Introducción 2. Objetivo del TFG 3. Especificaciones del sistema 4. Funcionalidad del sistema 5. Hardware 6. Software 7. Modelo 3D 8. Verificación y demostración 9. Conclusiones y líneas futuras

## Software

Diseño orientado a objeto


- Relación con el objeto físico
- Estructura modular y organizada
- Capa de abstracción
- Exportable y reutilizable

## Software


## Sumario

### 1. Introducción 2. Objetivo del TFG 3. Especificaciones del sistema 4. Funcionalidad del sistema 5. Hardware 6. Software 7. Modelo 3D 8. Verificación y demostración 9. Conclusiones y líneas futuras

## Modelo 3D


Modelo CAD | Modelo Real

Prototipo realizado

## Sumario

### 1. Introducción 2. Objetivo del TFG 3. Especificaciones del sistema 4. Funcionalidad del sistema 5. Hardware 6. Software 7. Modelo 3D 8. Verificación y demostración 9. Conclusiones y líneas futuras

## Verificación y demostración


Verificación del prototipo: Sistema a controlar

Control del ordenador

## Verificación y demostración

Verificación del prototipo: Digispark


## Verificación y demostración

Verificación del prototipo: Periférico de control


## Verificación y demostración

# Demostración SWNUI como ratón

## Verificación y demostración

# Demostración SWNUI como teclado

## Sumario

### 1. Introducción 2. Objetivo del TFG 3. Especificaciones del sistema 4. Funcionalidad del sistema 5. Hardware 6. Software 7. Modelo 3D 8. Verificación y demostración 9. Conclusiones y líneas futuras

## Conclusiones y líneas futuras

Conclusiones:

- Tecnologías MEMs y Bluetooth Low Energy
- Sistemas de reconocimiento de gestos ópticos vs no ópticos
- Reconocimiento gestual en dispositivos wearables

Trabajo futuro:

- Mejorar el bajo consumo
- Mejorar la parte mecánica (tamaño y apariencia)
- Transformar el prototipo en producto
- System On Chip

Sistema de reconocimiento

gestual

## Trabajo Fin de Grado

Realizado por: José Miguel Ríos Rubio Dirigido por: Francisco Javier Vizcaíno Martín

Departamento de Tecnología Electrónica - UNIVERSIDAD DE MALAGA Málaga, 16 de julio de 2015

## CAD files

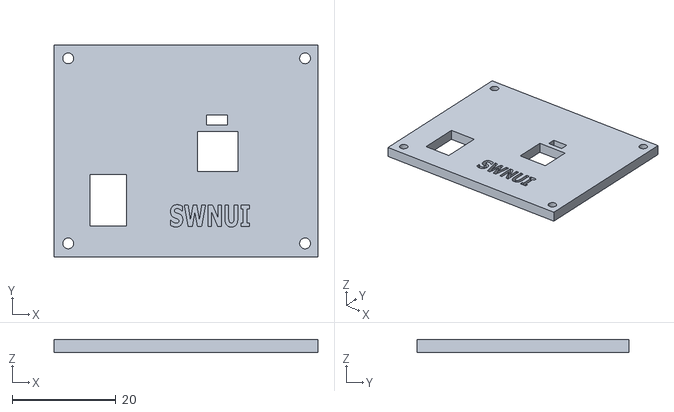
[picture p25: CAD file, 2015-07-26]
Project/3DModel/3d_printer/tapa.obj
51.0 x 41.0 x 2.50

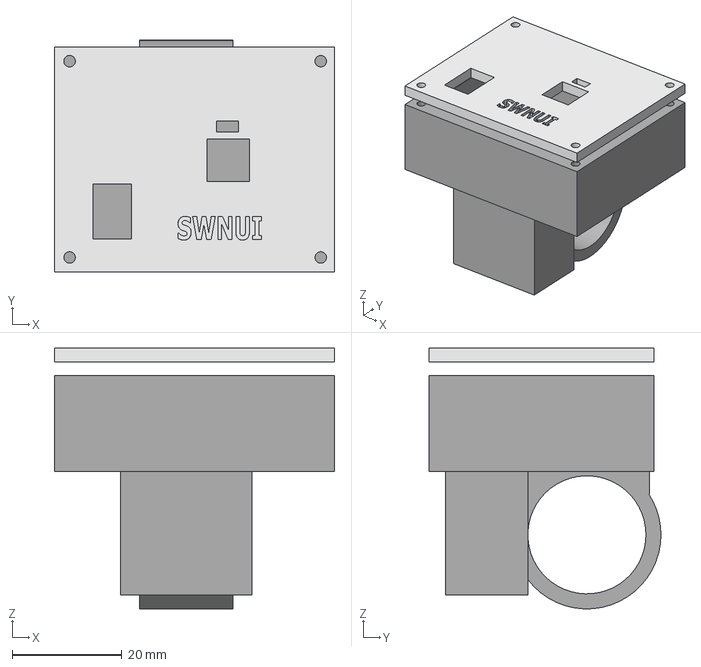
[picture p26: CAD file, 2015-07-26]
Project/3DModel/Freecad/TFG.FCStd
51.0 x 42.3 x 47.5 mm
Tapa
SWNUI_v2

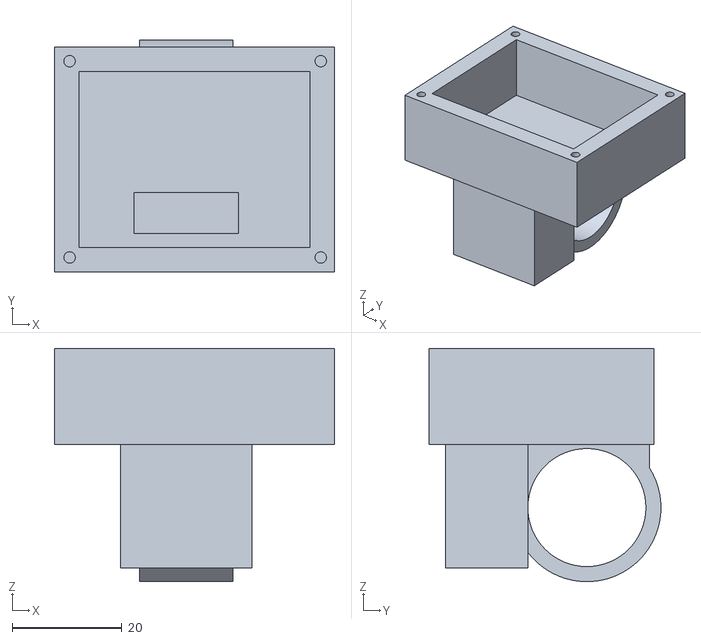
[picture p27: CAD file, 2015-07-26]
Project/3DModel/3d_printer/caja.obj
51.0 x 42.3 x 42.5

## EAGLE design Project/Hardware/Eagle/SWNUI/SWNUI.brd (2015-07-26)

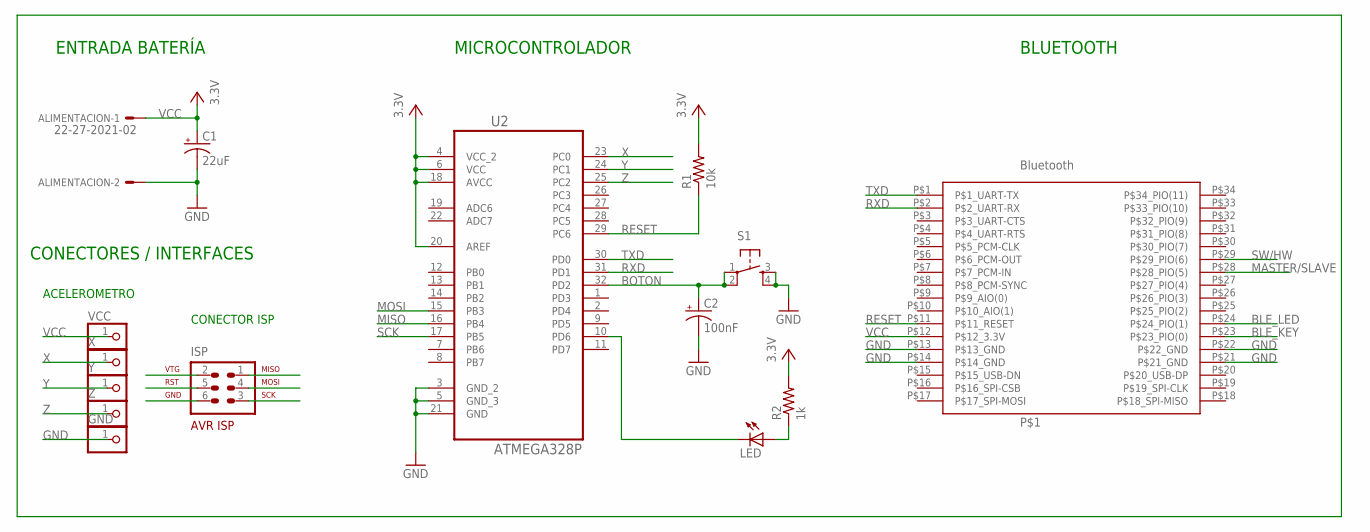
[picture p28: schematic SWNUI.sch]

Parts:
ALIMENTACION: 22-27-2021-02; 6410-02
C1: 22uF; EIA3216
C2: 100nF; EIA3216
GND: PINHD-1X1; 1X01
ISP: AVR-ISP-6
LED: LEDCHIP-LED0805; CHIP-LED0805
P$1: Bluetooth; BTM400
R1: 10k; 0805
R2: 1k; 0805
S1: TAC_SWITCHPTH; TACTILE-PTH
U2: ATMEGA328P; QFP80P900X900X120-32N
VCC: PINHD-1X1; 1X01
X: PINHD-1X1; 1X01
Y: PINHD-1X1; 1X01
Z: PINHD-1X1; 1X01

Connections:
BLE_KEY: P$1.P$23 (P$23_PIO(0))
BLE_LED: P$1.P$24 (P$24_PIO(1))
BOTON: C2.A (+), S1.1, S1.2, U2.32 (PD2)
GND: ALIMENTACION.2, C1.C (-), C2.C (-), GND.1, ISP.6, P$1.P$13 (P$13_GND), P$1.P$14 (P$14_GND), P$1.P$21 (P$21_GND), P$1.P$22 (P$22_GND), S1.3, S1.4, U2.3 (GND_2), U2.5 (GND_3), U2.21 (GND)
MASTER/SLAVE: P$1.P$28 (P$28_PIO(5))
MISO: ISP.1, U2.16 (PB4)
MOSI: ISP.4, U2.15 (PB3)
unnamed: LED.C, U2.10 (PD6)
unnamed: LED.A, R2.1
RESET: ISP.5, P$1.P$11 (P$11_RESET), R1.1, U2.29 (PC6)
RXD: P$1.P$2 (P$2_UART-RX), U2.31 (PD1)
SCK: ISP.3, U2.17 (PB5)
SW/HW: P$1.P$29 (P$29_PIO(6))
TXD: P$1.P$1 (P$1_UART-TX), U2.30 (PD0)
VCC: ALIMENTACION.1, C1.A (+), ISP.2, P$1.P$12 (P$12_3.3V), R1.2, R2.2, U2.4 (VCC_2), U2.6 (VCC), U2.18 (AVCC), U2.20 (AREF), VCC.1
X: U2.23 (PC0), X.1
Y: U2.24 (PC1), Y.1
Z: U2.25 (PC2), Z.1

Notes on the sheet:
CONECTOR ISP
ACELEROMETRO
MICROCONTROLADOR
ENTRADA BATERÍA
CONECTORES / INTERFACES
BLUETOOTH

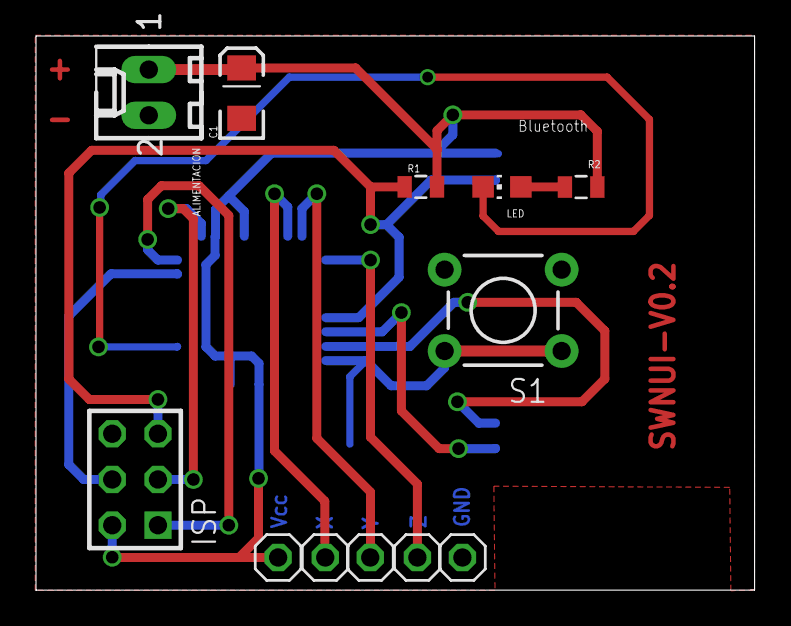
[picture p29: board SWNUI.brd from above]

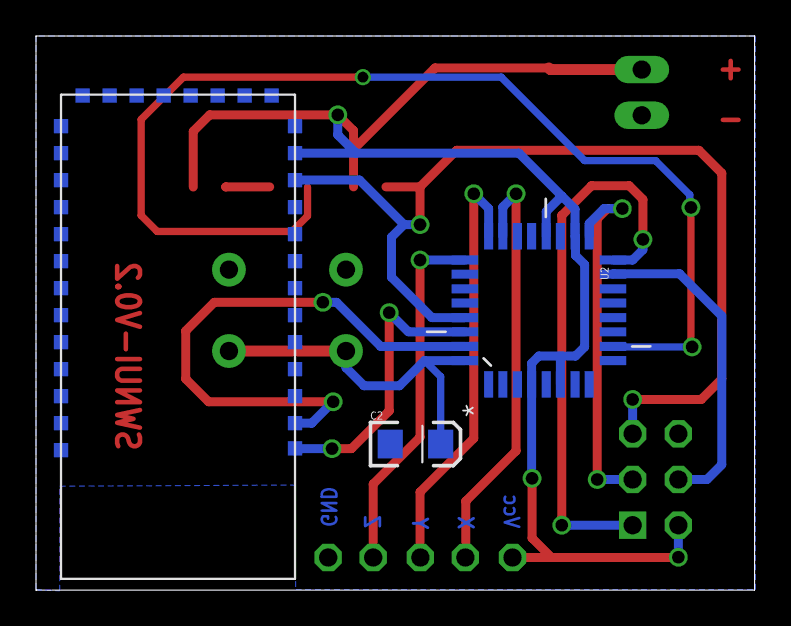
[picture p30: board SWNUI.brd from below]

Board: 2 copper layers, 39.9 x 30.8 mm, 15 parts (3 on the bottom side), 14 nets.

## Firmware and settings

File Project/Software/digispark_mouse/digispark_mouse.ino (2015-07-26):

/****************************************************************************************************************/
/* Programa: SWNUI_mouse                                                                                        */
/* Descripcion: Programa que recibe por el puerto serie (modulo BLE) muestras relacionadas con el movimiento    */
/* del SWNUI y las interpreta para gestionar el control del cursor del ordenador (dispositivo HID-USB mediante  */
/* V-USB).                                                                                                      */
/* Version: 04                                                                                                  */
/****************************************************************************************************************/

// LIBRERIAS
#include <TinyPinChange.h>
#include <SoftSerial.h>
#include <DigiMouse.h>

// CONSTANTES
#define BLE_TIMEOUT 10000             // Tiempo de conexion del modulo bluetooth
#define MOUSE_VELOCITY 1              // Paso (pixeles) con el que se incrementa la velocidad del cursor
#define MAX_MOUSE_VELOCITY 10         // Velocidad maxima que se alcanza en el desplazamiento del cursor
#define TIEMPO_ENTRE_CLICKS 100       // Tiempo de espera entre clicks (en ms)
#define P_RX 0                        // Pin de recepcion (puerto serie)
#define P_TX 1                        // Pin de transmision (puerto serie)
#define CON 'A'                       // Comando de conexion establecida
#define NUL 'N'                       // Comando de movimiento nulo (no movimiento)
#define UMOVE 'O'                     // Comando de movimiento hacia arriba
#define DMOVE 'P'                     // Comando de movimiento hacia abajo
#define LMOVE 'I'                     // Comando de movimiento hacia la izquierda
#define RMOVE 'U'                     // Comando de movimiento hacia la derecha
#define CLI 'C'                       // Comando de click izquierdo

#define BMOVE 'A' // Back Move
#define FMOVE 'S' // Forward Move

#define RSIDE 'E' // Right Side
#define LSIDE 'R' // Left Side
#define USIDE 'T' // Up Side
#define DSIDE 'Y' // Down Side

  
// VARIABLES
char mx, my, mz, mov;                 // Comandos de movimiento
int c_mx, c_my;                       // Cantidad de movimiento
bool c_click;                         // Click del cursor
unsigned long t0;                     // Tiempo cero

// OBJETOS
SoftSerial BLE(P_RX, P_TX);           // Puerto serie software para el control del modulo BLE

/****************************************************************************************************************/

// PROTOTIPO DE FUNCIONES
void inicializar_datos();             // Inicializa las variables (de recepcion y movimiento)
void conectar_BLE();                  // Inicializa el puerto serie y se conecta al modulo esclavo
void inicializar_raton();             // Inicializa el control del cursor (HID-USB)
bool muestras_disponibles();          // Determina si hay muestras disponibles en el puerto serie
void leer_muestras();                 // Lee las muestras del puerto serie
void determinar_movimiento();         // Determina el movimiento a realizar a partir de las muestras adquiridas
void determinar_click();              // Determina si ha de producirse un click
void actualizar_cursor();             // Actualiza la posicion del cursor y mantiene con vida el periferico USB
void click_izquierdo();               // Realiza un click izquierdo (presiona y suelta)
void tiempo_cero();                   // Establece el momento inicial
unsigned long tiempo_transcurrido();  // Determina el tiempo transcurrido desde el momento inicial

/****************************************************************************************************************/

// PROGRAMA PRINCIPAL
void setup()
{
    inicializar_datos();
    inicializar_raton();
    conectar_BLE();
}

void loop()
{
    if(muestras_disponibles())
    {
        leer_muestras();
        determinar_movimiento();
        determinar_click();
    }
    actualizar_cursor();
}

/****************************************************************************************************************/

// FUNCIONES
void inicializar_datos()
{
    mov = NUL;
    mx = NUL;
    my = NUL;
    mz = NUL;
    c_mx = 0;
    c_my = 0;
    c_click = false;
    t0 = 0;
}

void conectar_BLE()
{
    BLE.begin(9600);

    BLE.print("at+conn00,15,83,00,12,51\r\n");
    DigiMouse.delay(BLE_TIMEOUT);
    BLE.write(CON);
}

void inicializar_raton()
{
    DigiMouse.begin();
}

bool muestras_disponibles()
{
    bool md;
    
    if(BLE.available() >= 3)
        md = true;
    else
        md = false;
        
    return md;
}

void leer_muestras()
{
    mx = BLE.read();
    my = BLE.read();
    mz = BLE.read();
}

void determinar_movimiento()
{
    if(mx == RSIDE)
    {
        if(c_mx < MAX_MOUSE_VELOCITY)
            c_mx = c_mx + MOUSE_VELOCITY;
    }
    else if(mx == LSIDE)
    {
        if(c_mx > -MAX_MOUSE_VELOCITY)
            c_mx = c_mx - MOUSE_VELOCITY;
    }
    else
        c_mx = 0;
    
    if(my == DSIDE)
    {
        if(c_my < MAX_MOUSE_VELOCITY)
            c_my = c_my + MOUSE_VELOCITY;
    }
    else if(my == USIDE)
    {
        if(c_my > -MAX_MOUSE_VELOCITY)
            c_my = c_my - MOUSE_VELOCITY;
    }
    else
        c_my = 0;
}

void determinar_click()
{
    if((mz == CLI) && (tiempo_transcurrido() >= TIEMPO_ENTRE_CLICKS))
    {
        c_click = true;
        tiempo_cero();
    }
    else
        c_click = false;
}

void actualizar_cursor()
{
    if(c_click == true)
    {
        click_izquierdo();
        c_click = false;
        tiempo_cero();
    }
    
    DigiMouse.move(c_mx, c_my, c_click);
    
    DigiMouse.update();
}

void click_izquierdo()
{
    DigiMouse.setButtons(1<<0); // Click
    DigiMouse.delay(10);
    DigiMouse.setButtons(0); // Unclick
}

void tiempo_cero()
{
    t0 = millis();
}

unsigned long tiempo_transcurrido()
{
    return (millis() - t0);
}

/****************************************************************************************************************/

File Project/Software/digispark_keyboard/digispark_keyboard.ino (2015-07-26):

/****************************************************************************************************************/
/* Programa: SWNUI_keyboard                                                                                     */
/* Descripcion: Programa que recibe por el puerto serie (modulo BLE) muestras relacionadas con el movimiento    */
/* del SWNUI y las interpreta para gestionar el control del teclado del ordenador (dispositivo HID-USB mediante */
/* V-USB).                                                                                                      */
/* Version: 01                                                                                                  */
/****************************************************************************************************************/

// LIBRERIAS
#include <TinyPinChange.h>
#include <SoftSerial.h>
#include "DigiKeyboard.h"

// CONSTANTES

#define P_RX 0                        // Pin de recepcion (puerto serie)
#define P_TX 1                        // Pin de transmision (puerto serie)
#define PPM 420                       // Pulsaciones Por Minuto
#define PPS PPM/60                    // Pulsaciones Por Segundo
#define TEP 1000/PPS                  // Tiempo entre pulsaciones
#define BLE_TIMEOUT 10000             // Tiempo de conexion del modulo bluetooth
#define GEST_OK '1'                   // Comando OK correspondiente a la tecla F5
#define GEST_CANCEL '2'               // Comando OK correspondiente a la tecla escape
#define GEST_NEXT '3'                 // Comando NEXT correspondiente a la flecha derecha
#define GEST_PREV '4'                 // Comando PREV correspondiente a la flecha izquierda
#define CON 'A'                       // Comando de conexion establecida
#define NUL 'N'                       // Comando nulo

// VARIABLES
char cmd;                             // Comando (gesto)

// OBJETOS
SoftSerial BLE(P_RX, P_TX);           // Puerto serie software para el control del modulo BLE

/****************************************************************************************************************/

// PROTOTIPO DE FUNCIONES
void conectar_BLE();                  // Inicializa el puerto serie y se conecta al modulo esclavo
bool datos_disponibles();             // Determina si hay datos disponibles en el puerto serie
void leer_dato();                     // Lee el dato del puerto serie
void determinar_tecla();              // Determina y simula la tecla a presionar, a partir del comando recibido
void tecla(unsigned int t);           // Realiza la pulsacion de la tecla t
void actualizar_teclado();            // Mantiene con vida el periferico USB

/****************************************************************************************************************/

// PROGRAMA PRINCIPAL
void setup()
{
    conectar_BLE();
}


void loop()
{
    if(datos_disponibles())
    {
        leer_dato();
        determinar_tecla();
    }
    actualizar_teclado();
}

/****************************************************************************************************************/

// FUNCIONES

void conectar_BLE()
{    
    BLE.begin(9600);

    BLE.print("at+conn00,15,83,00,12,51\r\n");
    DigiKeyboard.delay(BLE_TIMEOUT);
    BLE.write(CON);
}

bool datos_disponibles()
{
    bool md;
    
    if(BLE.available())
        md = true;
    else
        md = false;
        
    return md;
}

void leer_dato()
{
    cmd = BLE.read();
}

void actualizar_teclado()
{
    DigiKeyboard.update();
}

void determinar_tecla()
{
    if(cmd == GEST_NEXT)
        tecla(KEY_ARROW_RIGHT);
    else if(cmd == GEST_PREV)
        tecla(KEY_ARROW_LEFT);
    else if(cmd == GEST_OK)
        tecla(KEY_F5);
    else if(cmd == GEST_CANCEL)
        tecla(KEY_ESC);
}

void tecla(unsigned int t)
{
    DigiKeyboard.sendKeyStroke(t);
    DigiKeyboard.delay(TEP);
}

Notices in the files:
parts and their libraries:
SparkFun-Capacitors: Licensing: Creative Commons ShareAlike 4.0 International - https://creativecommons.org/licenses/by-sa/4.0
